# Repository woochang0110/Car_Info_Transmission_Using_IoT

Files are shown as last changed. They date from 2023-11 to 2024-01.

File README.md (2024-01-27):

# Car_Info_Transmission_Using_IoT
## IoT를 이용한 차량 정보 전송 및 활용<br><br>

아래 사진을 누르면 발표자료 페이지로 이동합니다.
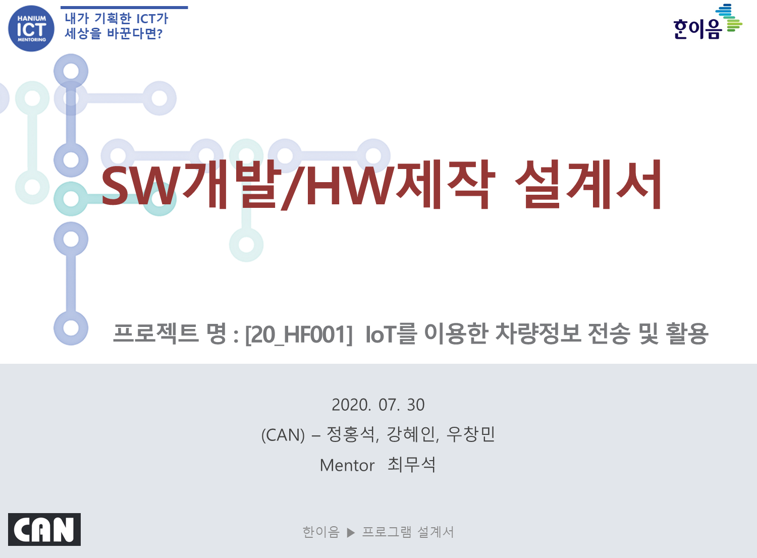
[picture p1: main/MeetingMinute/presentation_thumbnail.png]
Project Presentation
<br>
<br>

아래 사진을 누르면 프로젝트 개요서 페이지로 이동합니다.
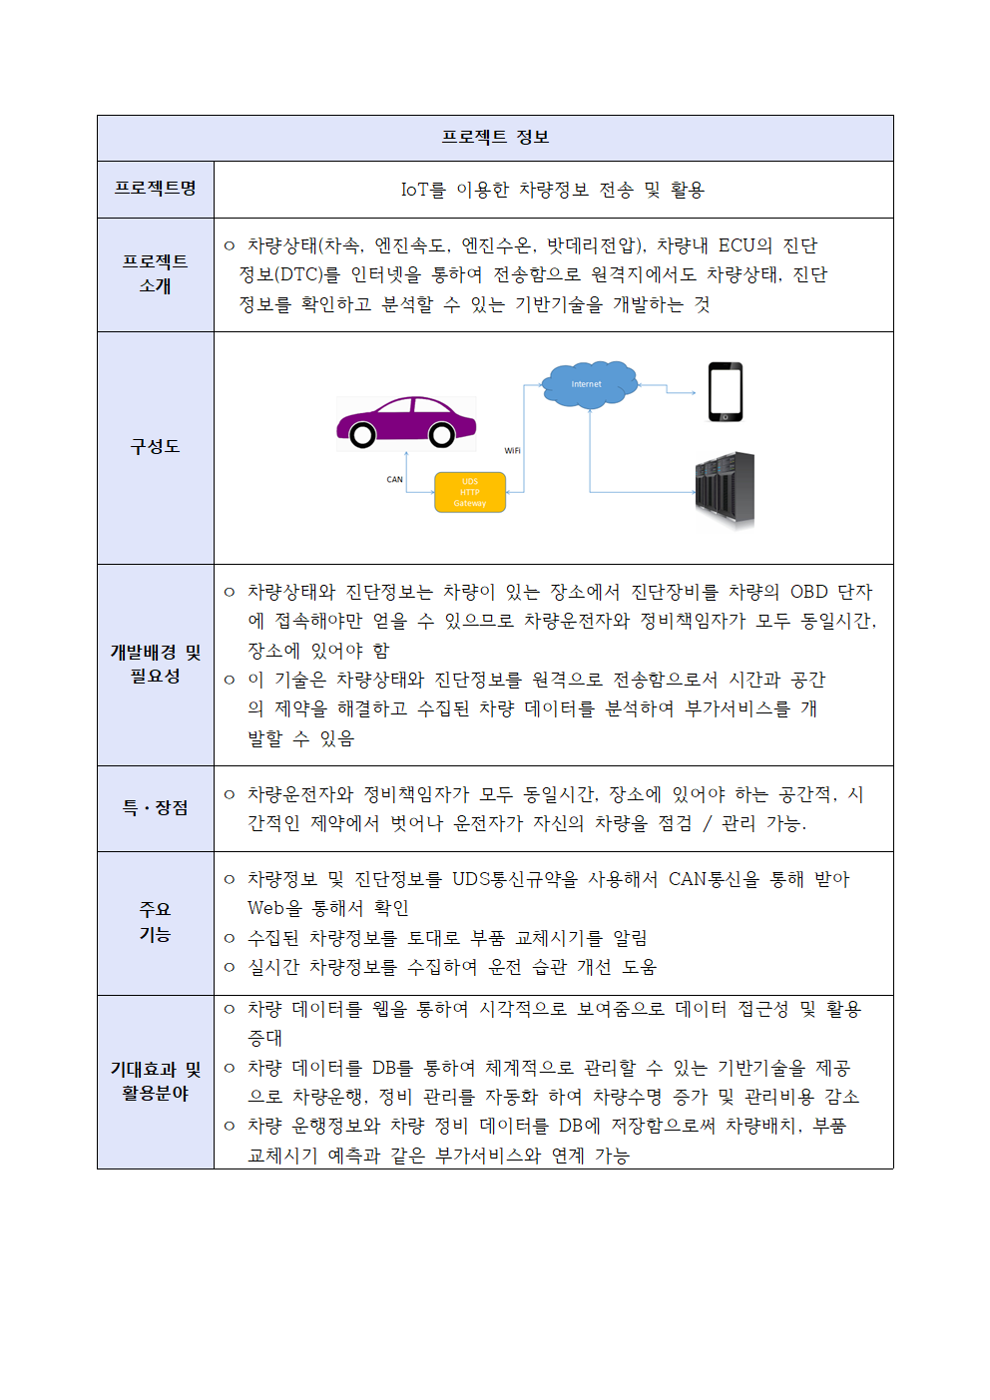
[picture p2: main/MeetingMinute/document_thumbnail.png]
<br>
<br>

아래 사진을 누르면 프로젝트 논문 페이지로 이동합니다.
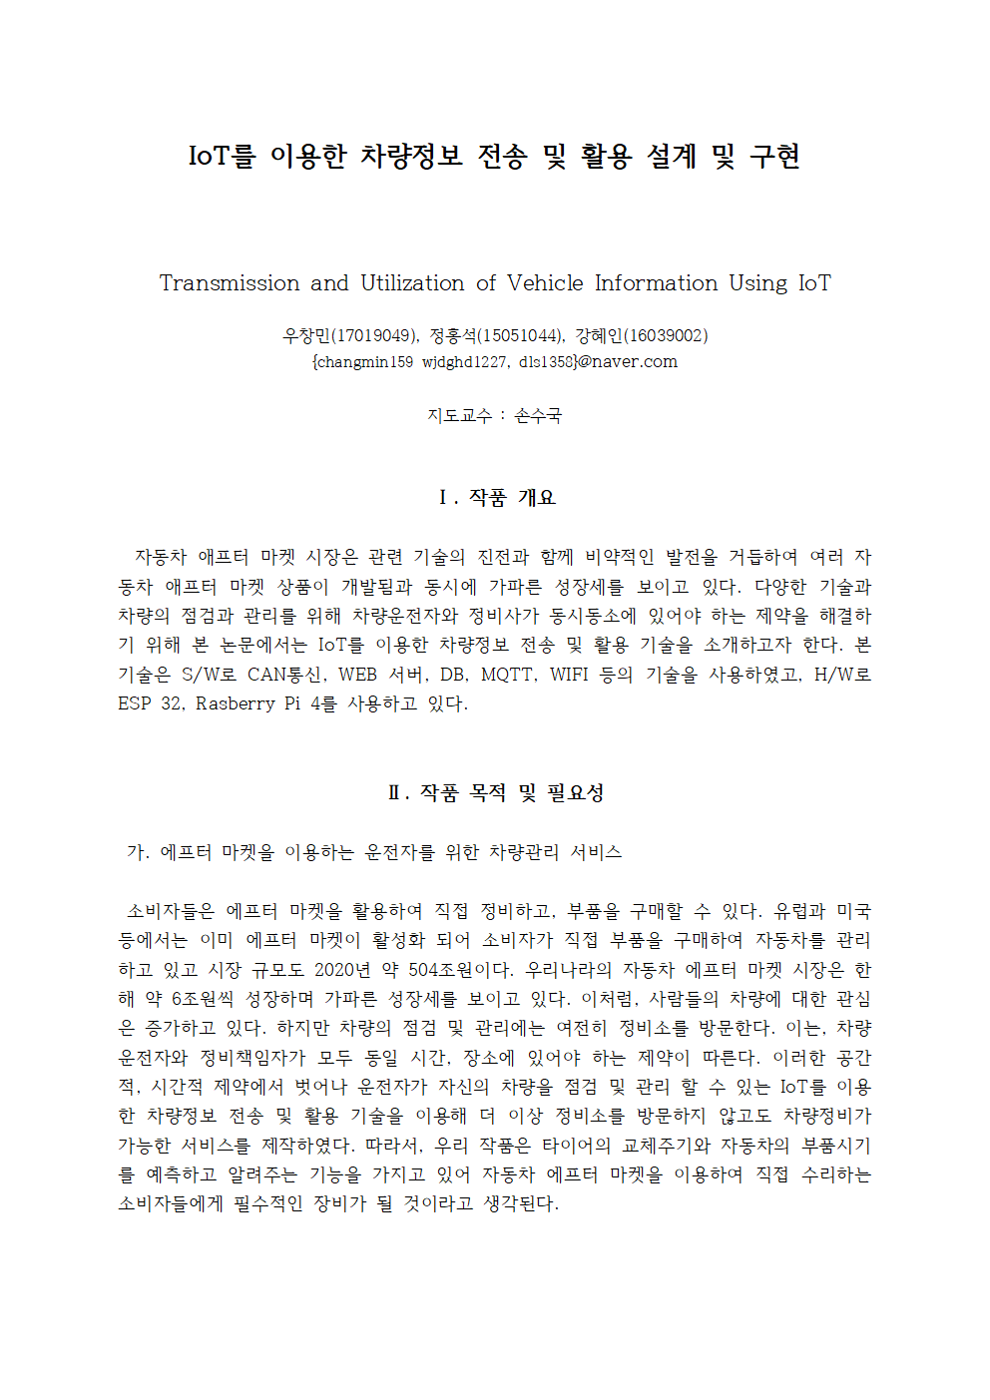
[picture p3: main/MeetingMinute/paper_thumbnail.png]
<br>
<br>

아래 사진을 누르면 데모 영상 링크로 이동합니다.
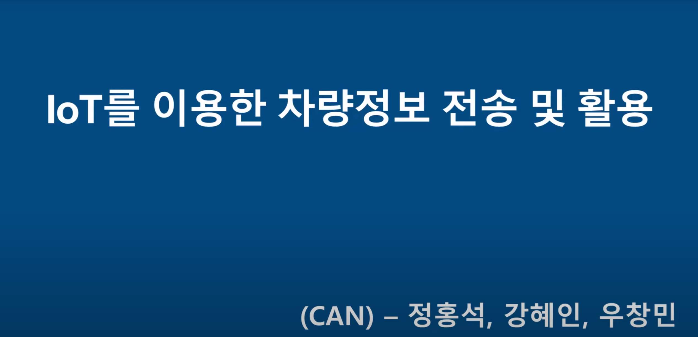
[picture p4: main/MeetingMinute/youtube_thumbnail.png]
Youtube (https://youtu.be/HxeCA7awFlk?si=O_MYcT4yE5AFmc94)
<br>

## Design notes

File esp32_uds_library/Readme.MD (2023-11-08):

ISO 14229-1 UDS protocol implementation for Arduino

This implementation requires ESP32_CAN lib

and ISO-TP-ESP32 lib from

Currently implemented:

* Send UDS SID with Userpayload
* Handle UDS Timeout
* Handle UDS Error

Missing:

* The Future will show

See usage example in example/uds/uds.ino
Request supported OBD2 PIDs see example/obd2/obd2.ino

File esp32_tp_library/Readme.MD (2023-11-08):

ISO 15765-2 ISO-TP protocol implementation for Arduino

This implementation requires ESP32 CAN library base on

...\Arduino\hardware\espressif\esp32\tools\sdk\include\driver\driver

Currently implemented:

* 11 bit standard CAN messages
* Send ISO-TP single frame messages
* Send ISO-TP multi frame messages using first and consecutive frames
* Evaluate flow controll and honour minimum separation time + block size during send
* Receive ISO-TP single frame messages
* Receive ISO-TP multi frame messages
* Send flow controll as configured in message (minimum separation time + block size)
* Session timeout
* FC timeout
* CF timeout
* Timeout after too many FC Wait messages
* some error handling
* simple frame padding with 0x00

See usage example in example/send_receive/send_receive.ino

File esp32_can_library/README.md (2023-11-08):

This ESP32 CAN librry base on

...\Arduino\hardware\espressif\esp32\tools\sdk\include\driver\driver

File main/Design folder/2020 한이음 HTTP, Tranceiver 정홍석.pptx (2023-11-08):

## 2020 한이음 IoT를 이용한 차량정보 조회 및 활용

SW 블록 다이어그램 및 플로우 차트

## SW FlowChart

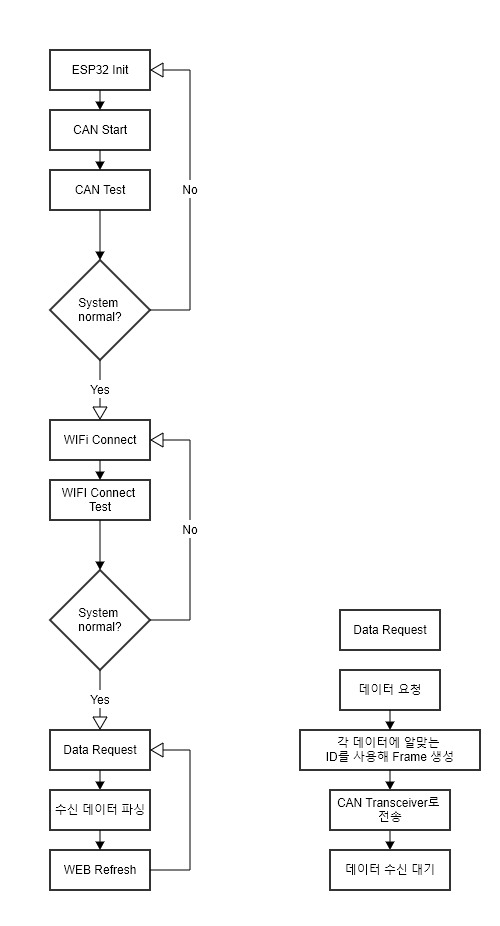
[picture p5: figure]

## 블록 다이어그램

<CAN Frame>

ID
(11bits)
(29bits)

DLC
(4bits)

Data

<CAN Message Frame>

ESP32

CAN Controller

CAN Transceiver

Tx

Rx

CAN_H

CAN_L

## 시스템 구성도

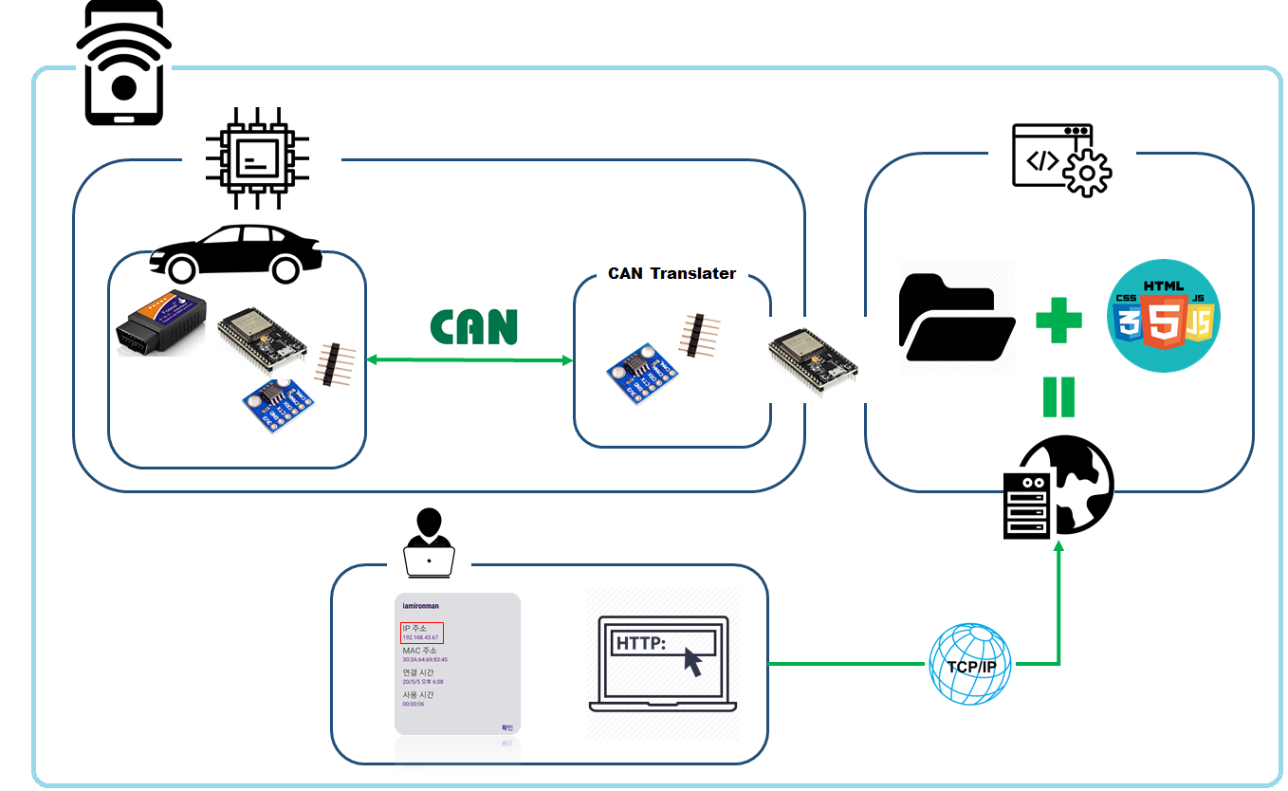
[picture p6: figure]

## SW 아키텍처

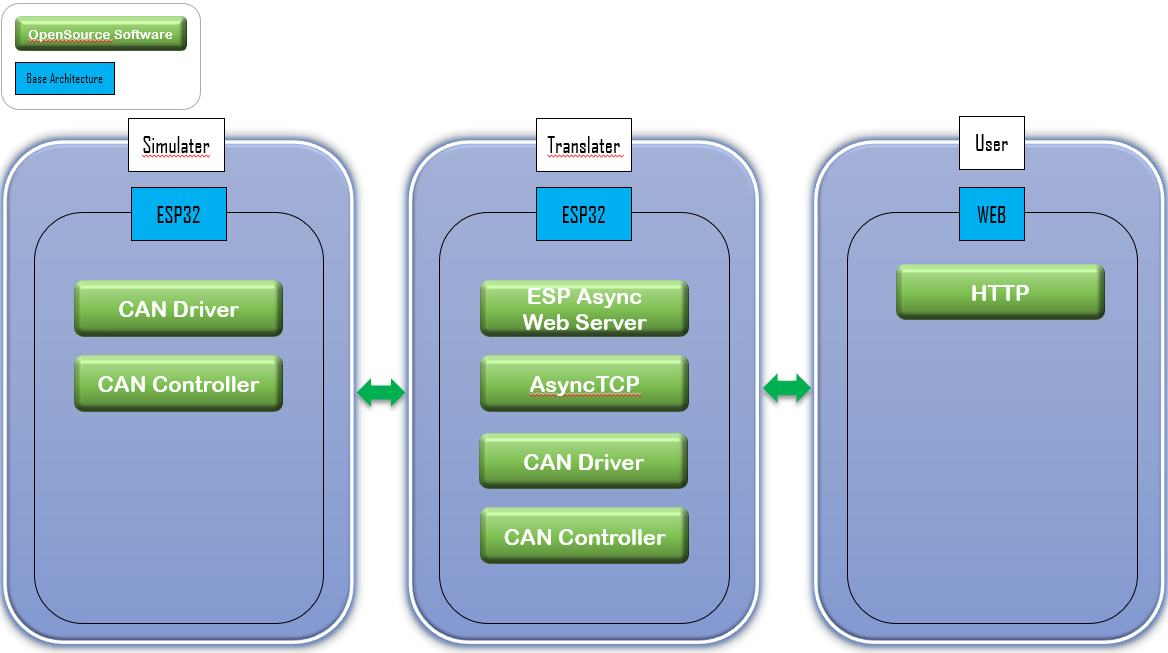
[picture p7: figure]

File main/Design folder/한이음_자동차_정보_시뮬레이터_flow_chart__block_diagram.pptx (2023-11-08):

## 자동차 정보 시뮬레이터

멘티 우창민

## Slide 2

시작

CAN 통신 가능?

YES

YES

YES

NO

IGN ON?

NO

RPM,주행거리,차속,연료잔량 값 세팅

RPM,주행거리,차속,연료잔량 값 임시저장

고장코드 값 임시저장

전송요청?

NO

임시 저장한 값들 전송

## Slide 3

스위치

버튼

IGN

고장코드

13

16

power

ESP-32

CAN

ESP-32

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
가변저항

가변저항

가변저항

가변저항

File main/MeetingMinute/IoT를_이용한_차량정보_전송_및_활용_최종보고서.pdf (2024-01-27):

- 1 -

# □ 서식4_한이음 ICT멘토링 프로젝트 결과보고서

2020 | 한이음 ICT멘토링
프로젝트명 | IoT를 이용한 차량정보 전송 및 활용

- 2 -

# 요 약 본

## 프로젝트 정보

주제영역 | ■ 생활 □ 업무 ■ 공공/교통 □ 금융/핀테크 □ 의료 □ 교육 □ 유통/쇼핑 □ 엔터테인먼트
기술분야 | ■ IoT □ 모바일 □ 데스크톱 SW □ 인공지능 □ 보안 □ 가상현실 □ 빅데이터 □ 자동제어기술 □ 블록체인 □ 영상처리
달성성과 | ■ 논문게재 및 포스터발표 □ 앱등록 □ 프로그램등록 □ 특허 □ 기술이전 □ 실용화 ■ 공모전(2020 한이음 공모전 ) □ 기타( )
프로젝트명 | IoT를 이용한 차량정보 전송 및 활용
프로젝트 소개 | ㅇ 차량상태(차속, 엔진속도, 엔진수온, 밧데리전압), 차량내 ECU의 진단 정보(DTC)를 인터넷을 통하여 전송함으로 원격지에서도 차량상태, 진단 정보를 확인하고 분석할 수 있는 기반기술을 개발하는 것
개발배경 및 필요성 | ㅇ 차량상태와 진단정보는 차량이 있는 장소에서 진단장비를 차량의 OBD 단 자에 접속해야만 얻을 수 있으므로 차량운전자와 정비책임자가 모두 동일 시간, 장소에 있어야 함 ㅇ 이 기술은 차량상태와 진단정보를 원격으로 전송함으로서 시간과 공간 의 제약을 해결하고 수집된 차량 데이터를 분석하여 부가서비스를 개 발할 수 있음
프로젝트 주요기능 | ㅇ 차량정보 및 진단정보를 UDS통신규약을 사용해서 CAN통신을 통해 받아 Web을 통해서 확인 ㅇ 수집된 차량정보를 토대로 부품 교체시기를 알림 ㅇ 실시간 차량정보를 수집하여 운전 습관 개선 도움
작품의 기대효과 및 활용분야 | ㅇ 차량 데이터를 웹을 통하여 시각적으로 보여줌으로 데이터 접근성 및 활용 증대 ㅇ 차량 데이터를 DB를 통하여 체계적으로 관리할 수 있는 기반기술을 제공 으로 차량운행, 정비 관리를 자동화 하여 차량수명 증가 및 관리비용 감소 ㅇ 차량 운행정보와 차량 정비 데이터를 DB에 저장함으로써 차량배치, 부품 교체시기 예측과 같은 부가서비스와 연계 가능

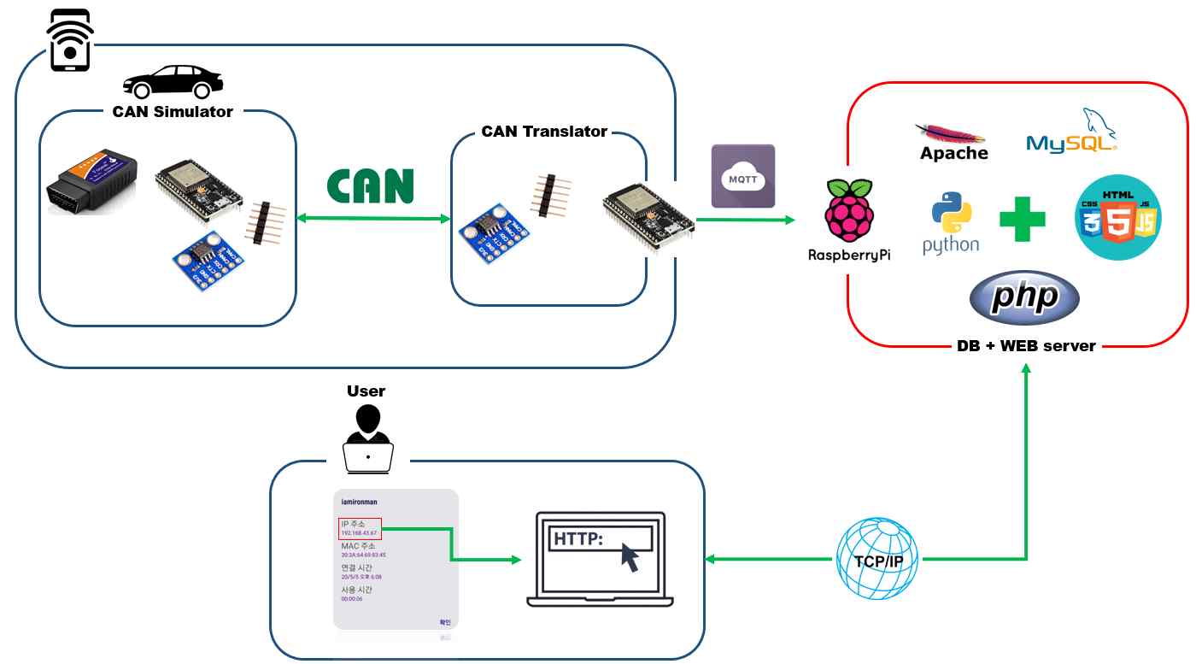
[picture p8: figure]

- 3 -

# (본문) 프로젝트 결과보고서

# Ⅰ. 프로젝트 개요

# 가. 프로젝트 소개

# ㅇ차량상태(차속, 엔진속도, 엔진수온, 밧데리전압), 차량내 ECU의 진단정보(DTC)를

# 인터넷을 통하여 전송함으로 원격지에서도 차량상태, 진단정보를 확인하고 분석할 수 있는 기반기술 개발하는 것

# 나. 개발배경 및 필요성

# ㅇ 차량상태와 진단정보는 차량이 있는 장소에서 진단장비를 차량의 OBD 단자에

# 접속해야만 얻을 수 있으므로 차량운전자와 정비책임자가 모두 동일시간, 장소

존재해야 함.

# ㅇ 접근성에서 가장 뛰어난 수단은 WEB이라 생각했고, WEB 서비스를 통해 차량

# 정보를 관제할 수 있는 시스템 개발 시작. ㅇ 이 프로젝트를 통해 차량상태와 진단정보를 MQTT를 이용해서 원격으로 전송

# 함으로서 시간과 공간의 제약을 해결하고 수집된 차량 데이터를 분석하여 부가 서비스를 개발 가능. 다. 작품 구성도

- 4 -

# 라. 작품의 특징 및 장점

ㅇ 차량운전자와 정비책임자가 모두 동일시간, 장소에 있어야 하는 공간적,

시간적인 제약에서 벗어나 운전자가 자신의 차량을 점검 / 관리 가능.

ㅇ 기존 기술인 OBD2를 이용해서 차량상태를 진단 및 데이터 저장.

ㅇ 수집된 데이터를 웹 페이지에서 시각적으로 표현.

ㅇ 총 주행거리 데이터를 사용해 차량의 부품 교체 시기 예측.

# Ⅱ. 프로젝트 수행결과

# 가. 업무분장

번호 | 성명 | 역할 | 담당업무
1 | 최무석 | 멘 토 | - 미팅 계획 수립, 멘토링
3 | 우창민 | 팀 장 | - SW1, 3D 프린팅
4 | 정홍석 | 팀 원2 | - SW2
5 | 강혜인 | 팀 원3 | - HW

# 나. 주요기능

구분 | 기능 | 설명
S/W | UDS 통신 | 차량상태를 받아오기 위해 차량과 UDS 통신. WIFI를 통한 DB와의 연동
| 받아온 데이터들을 DB에 저장. DB에 저장된 값들을 보여주기 위해 웹서버 활용. 웹 페이지 상에
| 출력 | 실시간 정보, 통계 페이지, 소모품 교체 주기, 고장코드 정보를 웹을 통해 출력
H/W | UDS, HTTP Translator 하드웨어 | - ESP32와 CAN transceiver로 구성되어 자동 차 CAN 네트워크 데이터를 WiFi 네트워크로 전송
| UDS Simulator 하드웨어 | - ESP32와 CAN transceiver로 구성되어 자동 차 상태정보, 진단정보를 시뮬레이션

- 5 -

# 다. 프로젝트 개발환경

구분 | 항목 | 적용내역
S/W 개발환경 | OS | Window10, Rasbian | 개발에 사용된 운영체제
| 개발환경(IDE) | Arduino IDE (1.8.9) | esp-32 개발 시 사용
| 개발도구 | Visual Studio Code | 코드 수정 시 사용
| 개발언어 | C++, Python, PHP, Javascript | 웹서버, DB 제작에 사용
H/W 구성장비 | 디바이스 | ESP32, CAN transceiver, 가변저항, 토글 스위치 | 프로젝트에 사용된 디바이스
| 센서 | x | x
| 통신 | CAN, OBD, UDS, MQTT | 차량과의 통신을 위해 사용한 통신 프로토콜
| 개발언어 | C++ | esp-32 개발에 사용된 언어

# 라. 장비(기자재/재료) 활용

번호 | 품명 | 작품에서의 주요기능
1 | ESP-32 | - 시뮬레이터, 트랜스레이터로 사용
2 | CJMCU-230 | - 캔 트랜시버로 사용
3 | 라즈베리파이 4 | - 웹서버, DB 구동에 사용
4 | 3D 프린터 | -3D 프린팅에 사용

# 마. 프로그램 작동 동영상

# ㅇ https://youtu.be/HxeCA7awFlk

# 바. 결과물 상세 이미지

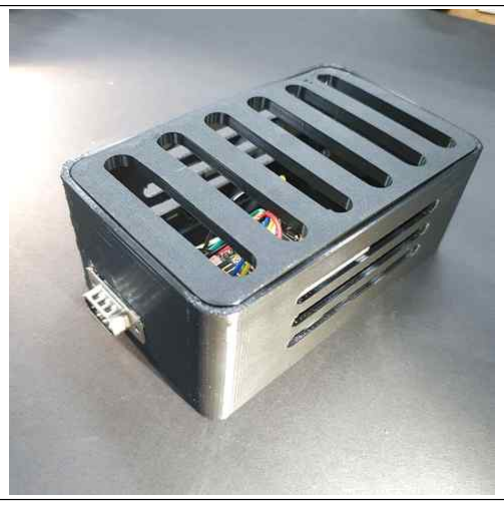
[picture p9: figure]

- 6 -

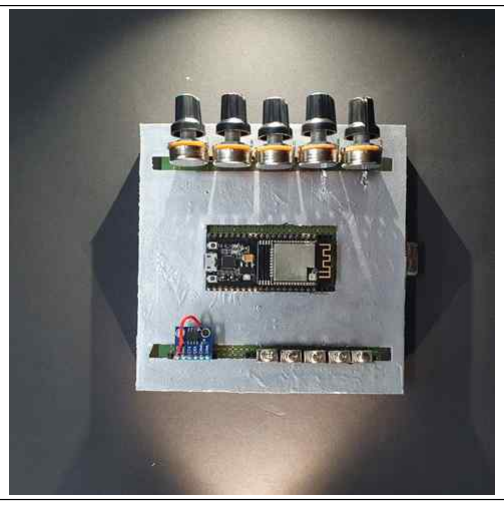
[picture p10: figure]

# 사. 달성성과

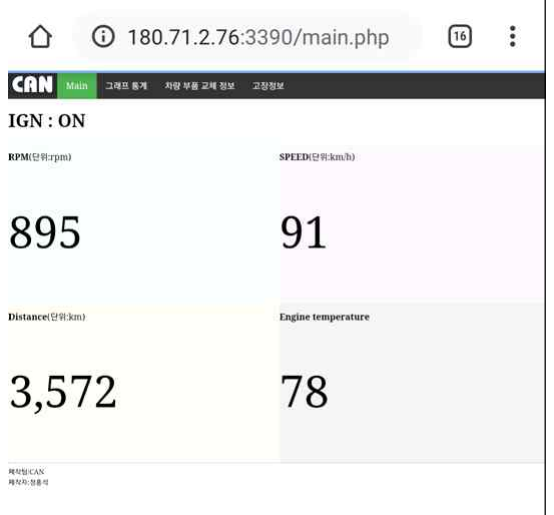
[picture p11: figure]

# ㅇ 기존 기획 의도대로 차량상태(차속, 엔진속도, 엔진수온, 밧데리전압), 차량내

# ECU의 진단정보(DTC)를 인터넷을 통하여 전송함으로 원격지에서도 차량상태, 진

단정보를 확인하고 분석할 수 있는 기반기술을 개발하는 성과를 달성하였음.

■

## 논문게재 및

### 포스터발표

게재(발표)자명 | 논문(포스터)명 | 게재(발표)처 | 게재(발표)일자
우창민 | IoT를 이용한 차량정보 전송 및 활용 설계 및
구현 | 한 국 정 보 처 리 학 회 2017. 00. 00.

□

### 앱(APP)

등록

등록자명 | 앱(APP)명 | 등록처 | 등록일자
| | | 2017. 00. 00.

□

### 프로그램

등록

등록자명 | 프로그램명 | 등록처 | 등록일자
| | | 2017. 00. 00.

□

## 특허/실용신안

출원

출원자명 | 특허/실용신안명 | 출원번호 | 출원일자
| | | 2017. 00. 00.

## □ 기술이전

기술이전기업명 | 기술명 | 금액 | 이전일자
| | | 2017. 00. 00.

### ■ 공모전

구분(교내/대외) | 공모전명 | 수상여부(출품/수상) | 상격
대외 | 2020 한이음 공모전 | 입선

## □ 실용화

## #실용화한 내용에 대한 구체적 작품설명

□ 기타

# Ⅲ. 프로젝트 수행방법

# 가. 프로젝트 수행일정

- 7 -
구분 | 추진내용 | 수행일정
3월 | 4월 | 5월 | 6월 | 7월 | 8월 | 9월 | 10월 | 11월
계획 | Kickoff 미팅, 팀구성, 업무분장, 개발계획 | | 11
분석 | UDS, HTTP gateway 기능분석 | | 20
설계 | HW1,2 회로설계 | | | 1
| SW1 설계 | | | 1
| SW2 설계 | | | 1
개발 | HW1,2 개발&3D 프린팅 | | | | 1
| SW1 개발 | | | | | 1
| SW2 개발 | | | | | 1
| 외부 서버 개발
테스트 | HW1과 SW1, HW2와 SW2 통합 테스트 | | | | | | | 1
종료 | 테스트결과 반영, 개선, 결과보고서 | | | | | | | | 31
오프라인 미팅계획 | Skype를 이용한 온라인 미팅 | | 25 | 9,23 | 6,20 | 4,18 | 2,15, 29 | 12,2 6 | 10,2 4 | x

# 나. 문제점 및 해결방안

# ㅇ 프로젝트 관리 측면

# *문제점

- 하드웨어 가공기술 및 공구부족으로 하드웨어 개발일정 지연.

# *해결방안

- 추가 공구(3D 프린터) 구매 및 가공기술 습득을 위해 시간 투자.

# ㅇ 작품 개발 측면

# *문제점 - CAN통신을 위한 CAN 모듈의 결함으로 인한 프로젝트 개발일정 지연. - 자동차 정보 수집용 서버를 외부에 설치하는 것으로 변경하여 추가개발일정

발생.

# *해결방안

- CAN Tranceiver 모듈의 Vref핀 전압을 증가시킴으로써 문제 해결.

# - 라즈베리파이를 이용해 MQTT 서버와 웹서버 구축하여 차량데이터 전송

효율을 높임.

- 8 -

# Ⅳ. 기대효과 및 활용분야

# ㅇ 차량 데이터를 웹을 통하여 시각적으로 보여줌으로 데이터 접근성 및 활용성

# 증대. ㅇ 차량 데이터를 DB를 통하여 체계적으로 관리할 수 있는 기반기술을 제공함으로

# 차량운행, 정비 관리를 자동화 하여 차량수명 증가 및 관리비용 감소. ㅇ 차량 운행정보와 차량 정비 데이터를 DB에 저장함으로써 차량배치, 부품 교체

시기 예측과 같은 부가서비스와 연계 가능.

# Ⅴ. 참고자료

# 가. 참고 및 인용자료

ㅇ Seo-Kyung Lee, Jae-Yong Lee, Dong-Hyun Kim, Kwang-Joo Choi,
Jae-IlJung,CAN | Communication | System | using CAN | Protocol, | Korea

# Information Processing Society, Republic of Korea, 2006, 4

# ㅇ M. Farsi, K. Ratcliff and M. Barbosa, "An overview of controller area

network," in Computing & Control Engineering Journal, vol. 10,

# no.3,pp.113-120,June 1999, doi: 10.1049/cce:19990304

- 9 -

# [별첨] 한이음 ICT멘토링 프로젝트 산출물

# 한이음 ICT멘토링 프로젝트 산출물

# 1. 한이음 공모전 입선 ······················································0

# 2. 2020 온라인 추계학술 발표대회 참가 ····················0

# 3. 소스코드 ··········································································0

# 1. 한이음 공모전 입선

# 2. 2020년 온라인 추계학술 발표대회 참가

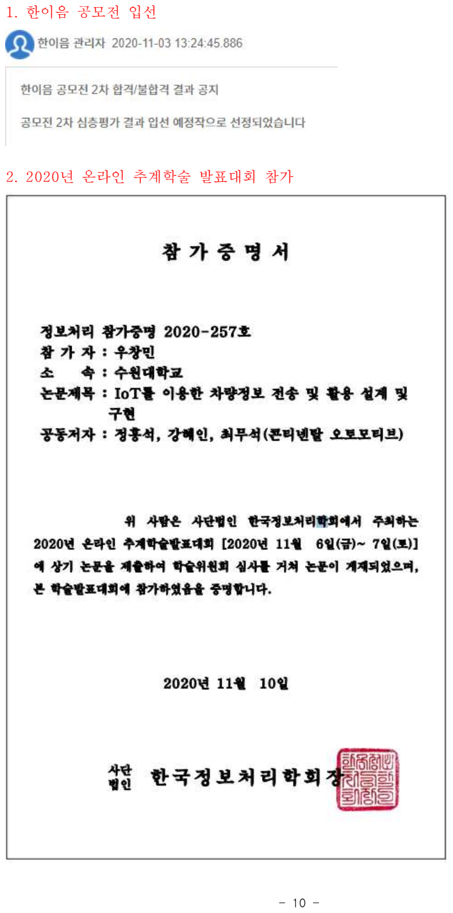
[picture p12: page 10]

- 10 -

- 11 -

# 3. 소스코드

## *CAR Simulator

#include <esp32_can.h>

#include <iso-tp-esp32.h>

#include <uds-esp32.h>

ESP32_CAN CAN0;
IsoTp isotp(&CAN0);
UDS uds(&isotp);
struct Session_t session;
//가변저항
const int CoolantTemp_pin = 34; const int Odometer_pin = 35; const int EngineRpm_pin = 32; const int VehicleSpeed_pin = 33; const int EngineFuelRate_pin = 25; //스위치
const int Error_Code1_pin = 5; const int Error_Code2_pin = 22; const int Error_Code3_pin = 18; const int IGN_pin = 21;
const int Auto_Simulator_pin = 19;
//함수
void AutoSimulator_OBD2(uint32_t Max, uint8_t bitarray[], int digit ); void AutoSimulator_UDS();
void hex_converter_8(uint32_t num, uint8_t bitarray[], int digit); //PID Data Array
uint8_t pidSupport0x01To0x20[] = {0x08, 0x18, 0x00, 0x00};
uint8_t pidSupport0x81To0xA0[] = {0x00, 0x00, 0x00, 0x08};
uint8_t pidSupport0xA1To0xC0[] = {0x04, 0x00, 0x00, 0x00};
uint8_t pid0x05CoolantTemp[] = {0x78}; // 0x78 = 120 => 120 - 40 = 80 C
uint8_t pid0x0CEngineRpm[] = {0x1F, 0x40}; // 0x1F 40 = 8000 => 8000/ 4 = 2000 rpm
uint8_t pid0x0DVehicleSpeed[] = {0x64}; // 0x64 = 100 Km/h
uint8_t pid0x9DEngineFuelRate[] = {0x3C}; //0x3C=60L
uint8_t pid0xA6Odometer[] = {0x00, 0x01, 0x86, 0xA0}; //0x00 01 86 A0=100000 =>100000/10=10000km //DTC Data Array
uint8_t P00BBFuelInjectorInsufficientFlow[] = {0x00, 0xBB};
uint8_t B0020LeftSideAirbagDeploymentControl[] = {0x80, 0x20};
uint8_t C0281BrakeSwitchCircuit[] = {0x42, 0x81};
//PID Struct
#define NUM_PIDS 8

struct {
uint8_t pid;
uint8_t* Data;
} responseData[NUM_PIDS] = { {0, pidSupport0x01To0x20}, {0x05, pid0x05CoolantTemp}, {0x0C, pid0x0CEngineRpm}, {0x0D, pid0x0DVehicleSpeed}, {0x80, pidSupport0x81To0xA0}, {0x9D, pid0x9DEngineFuelRate}, {0xA0, pidSupport0xA1To0xC0}, {0xA6, pid0xA6Odometer}

};
//DTC Struct
#define NUM_DTCS 3

struct {
int value;
uint8_t* Data;
} responseDTC[NUM_PIDS] = { {0, P00BBFuelInjectorInsufficientFlow}, {0, B0020LeftSideAirbagDeploymentControl}, {0, C0281BrakeSwitchCircuit}

};
void setup() {
// put your setup code here, to run once:

- 12 -

Serial.begin(115200);
// Initialize ESP32 CAN with a baudrate of 500kb/s and tx pin 16, rx pin 17. if (CAN0.begin(16, 17, CAN_500KBPS) == CAN_OK) {

Serial.println("ESP32 CAN Initialized Successfully!");
} else {
Serial.println("Error Initializing ESP32 CAN..."); return;
}
pinMode(5, INPUT); // 고장코드 1
pinMode(22, INPUT); // 고장코드 2 pinMode(18, INPUT); // 고장코드 3 pinMode(21, INPUT); // IGN ON pinMode(19, INPUT); //auto simulator delay(5000);
}#define LEN_DATA 8
void loop() {
uint8_t rxData[LEN_DATA];
uint8_t txData[LEN_DATA];
struct Session_t diag;
uint16_t retval = 0;
uint8_t pid;
int IGN = digitalRead(IGN_pin); if (!IGN) {//IGN OFF
Serial.println("IGN OFF");
}
else {//IGN ON
Serial.println("IGN ON");
int AutoSimul = digitalRead(Auto_Simulator_pin); if (!AutoSimul) {//Auto Simulator OFF Serial.println("Auto Simulator OFF"); Serial.println("Odometer ");
int reading_Odometer = analogRead(Odometer_pin); Serial.println(reading_Odometer);
uint32_t Odometer = reading_Odometer * 488; //실질적인 값을 표현하기 위해 Serial.println(Odometer);
hex_converter_8(Odometer, pid0xA6Odometer , 8);
Serial.println();
// TODO : Need to consider fomular, min, max of PDI tabale. //temperature=A-40

int reading_CoolantTemp = analogRead(CoolantTemp_pin); int CoolantTemp = map(reading_CoolantTemp, 0, 4095, 0, 255); Serial.println("Engine Temperature"); hex_converter_8(CoolantTemp, pid0x05CoolantTemp , 2); Serial.println();
//RPM =A-40
int reading_EngineRpm = analogRead(EngineRpm_pin);
uint16_t EngineRpm = map(reading_EngineRpm, 0, 4095, 0, 65535); Serial.println("Engine RPM");
hex_converter_8(EngineRpm, pid0x0CEngineRpm , 4); Serial.println();
int reading_VehicleSpeed = analogRead(VehicleSpeed_pin); int VehicleSpeed = map(reading_VehicleSpeed, 0, 4095, 0, 255); Serial.println("Vehicle Speed");
hex_converter_8(VehicleSpeed, pid0x0DVehicleSpeed , 2); Serial.println();
int reading_EngineFuelRate = analogRead(EngineFuelRate_pin); int EngineFuelRate = map(reading_EngineFuelRate, 0, 4095, 0, 60); Serial.println("Engine Fuel Rate");
hex_converter_8(EngineFuelRate, pid0x9DEngineFuelRate , 2); Serial.println();
responseDTC[1].value = digitalRead(Error_Code1_pin); responseDTC[2].value = digitalRead(Error_Code2_pin); responseDTC[3].value = digitalRead(Error_Code3_pin); }

- 13 -

else {//Auto Simulator ON
Serial.println("Auto Simulator ON"); AutoSimulator_OBD2(2000000, pid0xA6Odometer, 8 ); AutoSimulator_OBD2(255, pid0x05CoolantTemp, 2 ); AutoSimulator_OBD2(65535, pid0x0CEngineRpm, 4 ); AutoSimulator_OBD2(255, pid0x0DVehicleSpeed, 2 ); AutoSimulator_OBD2(60, pid0x9DEngineFuelRate, 2 ); AutoSimulator_UDS();
}
//Array에 data는 다 들어감
//-> DATA 전송
if (retval = uds.SessionServer(&diag))
{
Serial.println(F("No OBD request from tool.")); }
else
{
Serial.print(F("request SID: ")); Serial.println(diag.sid); //OBD2 DATA 전송
if (diag.sid == OBD_MODE_SHOW_CURRENT_DATA) { pid = diag.Data[0];
Serial.print(F("request PID: ")); Serial.println(pid); Serial.print(F("request data: "));
for (uint8_t i = 1; i < diag.len; i++)
{
Serial.print(diag.Data[i]); Serial.print(F(" ")); }
Serial.println();
memset(txData, 0, LEN_DATA);
for (uint8_t i = 0; i < NUM_PIDS; i++)
{
if (responseData[i].pid == pid) // Find the required pid data {
diag.sid = diag.sid + 0x40; // Add 0x40 to received sid txData[0] = pid;
uint8_t lenPidValue = sizeof(responseData[i].Data); memcpy(txData + 1, responseData[i].Data, lenPidValue); diag.Data = txData;
diag.len = lenPidValue + 1;
retval = uds.serverResponse(&diag);
}
}
}
//UDS 고장진단코드 전송
if (diag.sid == OBD_MODE_READ_DTC) { Serial.println("UDS start...");
int count = 0;// DTC 갯수
for (int i = 0; i < NUM_DTCS; i++) { if (responseDTC[i].value) { count++;
}
}
memset(txData, 0, 2 * count);
if (count == 0) {//DTC가 하나도 없을 때 Serial.println("No DTC");
diag.Data = 0;
diag.len = 4;
retval = uds.serverResponse(&diag);
}
else { //DTC 1개라도 있을떄
diag.sid = diag.sid + 0x40; // Add 0x40 to received sid
if (count == 1) {//DTC 1개
Serial.println(" 1 DTC");
for (int i = 0; i < NUM_DTCS; i++) {//on인 DTC 1개 찾아서 전송

- 14 -

if (responseDTC[i].value) {
uint8_t lenDTCValue = sizeof(responseDTC[i].Data); memcpy(txData, responseDTC[i].Data, lenDTCValue); diag.Data = txData;
diag.len = 2 * count;
retval = uds.serverResponse(&diag);
}
}
}//DTC 1개 close
else if (count == 2) {//DTC 2개 Serial.println(" 2 DTC ");
for (int i = 0; i < NUM_DTCS; i++) {
if (responseDTC[i].value) {
uint8_t lenDTCValue = sizeof(responseDTC[i].Data); memcpy(txData + 2 * i, responseDTC[i].Data, lenDTCValue); }
}
diag.Data = txData;
diag.len = 4;
retval = uds.serverResponse(&diag); }//DTC 2개 close
else if (count == 3) {//DTC 3개
Serial.println(" 3 DTC ");
for (int i = 0; i < NUM_DTCS; i++) {
uint8_t lenDTCValue = sizeof(responseDTC[i].Data); memcpy(txData + 2 * i, responseDTC[i].Data, lenDTCValue); }
diag.Data = txData;
diag.len = 6;
retval = uds.serverResponse(&diag); }//DTC 3개 close
}//DTC 1개라도 있을때 close
}//sid=dtc close
}
delay(1000);
}
}void AutoSimulator_OBD2(uint32_t Max, uint8_t bitarray[], int digit ) { uint32_t value = random(0, Max);
hex_converter_8(value, bitarray, digit);
}void AutoSimulator_UDS() {
for (int i = 0; i < NUM_DTCS; i++) {
responseDTC[i].value = random(0, 2);
}
}void hex_converter_8(uint32_t num, uint8_t bitarray[], int digit) { //들어온 값 , 값을 분해해서 넣을 배열, 배열이 8bit로 몇개 구성되어 있는지 int pos = digit;
int temp[digit] = { 0 }; // 16진수로 된 문자열을 임시저장할 배열 (순서 제대로임)
uint32_t decimal = num;
Serial.println();
for (int i = 0; i < pos; i++) {
if (decimal < 16) {
temp[pos - i - 1] = decimal;
}
temp[pos - i - 1] = decimal % 16;
decimal = decimal / 16;
Serial.print(temp[pos - i - 1]); Serial.print(" "); }
Serial.print(" 0x");
for (int j = 0; j < pos / 2; j++) {
bitarray[j] = temp[2 * j] * 16 + temp[2 * j + 1]; //int로 잘려져있는 값들을 8비트 배열에 차곡차곡 넣어줌 if (bitarray[j] < 16) {
Serial.print("0");
}
Serial.print(bitarray[j], HEX); Serial.print(" "); }

- 15 -

}

## *CAR Translator

# include <esp32_can.h>

# include <iso-tp-esp32.h> # include <uds-esp32.h>

# include <WiFi.h>

# include <PubSubClient.h>

# define MSG_BUFFER_SIZE (50) # define BUILTIN_LED 25

ESP32_CAN CAN0;
IsoTp isotp(&CAN0);
UDS uds(&isotp);
struct Session_t session;
char msg[MSG_BUFFER_SIZE];
const char* ssid = "Hong";
const char* password = "123456789q"; const char* mqtt_server = "180.71.2.76"; uint8_t tmp[] = {};
String packet;
long lastMsg = 0;
// 웹에 나타나는 정보 변수 초기화
int IGN = 0;
int RPM = 0;
int D = 0;
int V = 0;
int Eng_temp = 0;
int Fuel_level = 0;
WiFiClient esp_client;
PubSubClient client(esp_client); // 사용되는 함수 초기화
void displayWifistatus(void);
void OBD2_receiver(uint8_t pid);
void UDS_receiver(void);
long data_process(int count, uint8_t *array_pointer);
void mqtt_trans(int IGN, int (RPM), double D, int V, float Eng_temp, int Fuel_level); void callback(char* topic, byte* payload, unsigned int length);
void reconnect();
void setup() {
// put your setup code here, to run once: Serial.begin(115200);
Serial.println();
//1. wifi연결
WiFi.begin(ssid, password); Serial.println("Connecting");
while (WiFi.status() != WL_CONNECTED) {
displayWifistatus();
delay(500);
}
displayWifistatus();
Serial.println();
Serial.print("Conncected, IP address: "); Serial.println(WiFi.localIP()); Serial.print("Gateway IP: "); Serial.println(WiFi.gatewayIP()); Serial.print("RSSI: ");
Serial.println(WiFi.RSSI());
//2. Mqtt 연결
pinMode(BUILTIN_LED, OUTPUT); client.setServer(mqtt_server, 1883); client.setCallback(callback);

//3. CAN 연결

- 16 -
if (CAN0.begin(16, 17, CAN_500KBPS) == CAN_OK) { | //25,50,100,125,250,500,800,1000
Serial.println("ESP32 CAN Initialized Successfully!");
} else {
Serial.println("Error Initializing ESP32 CAN...");
return;
}
delay(5000);
}void loop() {
uint8_t pid[] = {0x1F, 0x05, 0x0C, 0x0D, 0x9D, 0xA6}; uint8_t uds_id[] = {};
//1. OBD2로 Data receive
for (int i = 0; i < sizeof(pid) / sizeof(uint8_t) ; i++) OBD2_receiver(pid[i]);
//2. UDS로 Data receive
UDS_receiver();
if (RPM != 0) | //엔진이 켜져있다면
IGN = 1; | //IGN을 True로
else | //엔진이 꺼져있다면
IGN = 0; | //IGN을 False로
if (IGN == 1); | //3. 시동이 켜져있다면
mqtt_trans(IGN); | //4. MQTT를 이용해 서버로 전송
}void displayWifistatus(void) {
Serial.print("ESP WiFi connection status: ");
switch (WiFi.status()) {
case 0:
Serial.println("WL_IDLE_STATUS"); break;
case 1:
Serial.println("WL_NO_SSID_AVAIL"); break;
case 3:
Serial.println("WL_CONNECTED"); break;
case 4:
Serial.println("WL_CONNECT_FAILED"); break;
case 6:
Serial.println("WL_DISCONNECTED"); break;
default:
Serial.println("Unknown status");
}
}void callback(char* topic, byte* payload, unsigned int length) { Serial.print("Message arrived [");
Serial.print(topic);
Serial.print("] ");
for (int i = 0; i < length; i++) { Serial.print((char)payload[i]);
}
Serial.println();
// Switch on the LED if an 1 was received as first character
if ((char)payload[0] == '1') {
digitalWrite(BUILTIN_LED, LOW); // Turn the LED on (Note that LOW is the voltage level // but actually the LED is on; this is because

// it is active low on the ESP-01)
} else {
digitalWrite(BUILTIN_LED, HIGH); // Turn the LED off by making the voltage HIGH }
}void reconnect() {
// Loop until we're reconnected
while (!client.connected()) { Serial.print("Attempting MQTT connection..."); // Create a random client ID
String clientId = "ESP8266Client-";

- 17 -

clientId += String(random(0xffff), HEX); // Attempt to connect
if (client.connect(clientId.c_str())) { Serial.println("connected");
// Once connected, publish an announcement... client.publish("start", "Connected Mqtt...");

// ... and resubscribe
client.subscribe("inTopic");
} else {
Serial.print("failed, rc="); Serial.print(client.state()); Serial.println(" try again in 5 seconds"); // Wait 5 seconds before retrying delay(5000);
}
}
}void OBD2_receiver(uint8_t pid) { int num = 0;
int count = 0;
long f_result = 0;
struct Session_t diag;
uint16_t retval = 0;
Serial.print(F("OBD2 request PIDs: ")); Serial.println(pid);
for (int i = 0; i < 1; i++) {
uint16_t rx_id_array[] = {0x7E9, 0x7E9};
diag.tx_id = 0x7DF; //0x7E0, 0x7DF -> 7DF였으면 원래 응답이 와야하는대 안됐음. // | 예제 하나 줄테니 실제 차량에서 진행해보자. //

diag.rx_id = rx_id_array[i];
Serial.print("tx_id : "); Serial.println(diag.tx_id); Serial.print("rx_id : "); Serial.println(diag.rx_id); //diag.rx_id = 0x7E8;
diag.sid = OBD_MODE_SHOW_CURRENT_DATA; diag.Data = &pid;
diag.len = 1;
if (retval = uds.Session(&diag))
{
Serial.print(F("OBD2 Error ")); Serial.print(retval);
Serial.print(F(" NRC "));
Serial.println(retval, HEX);
}
else
{
//0x1F, 0x05, 0x0C, 0x0D, 0x9D, 0xA6 //pid별 최대 바이트로 자르는 코드 시작
//1.각 pid별로 몇바이트인지 count변수에 저장 switch (pid) {
case 0x05:
count = 1;
//2. count만큼 데이터를 자르고 저장 tmp배열에 임시 저장 for (int i = 0; i < count; i++) {
tmp[i] = diag.Data[i];
}
//3. 데이터 후처리
Eng_temp = data_process(count, tmp) - 40; Serial.println("엔진 온도");
Serial.println(Eng_temp);
break;
case 0x0C:
count = 2;
//2. count만큼 데이터를 자르고 저장 tmp배열에 임시 저장 for (int i = 0; i < count; i++) {
tmp[i] = diag.Data[i];

- 18 -

}
//3. 데이터 후처리
RPM = data_process(count, tmp) / 4; Serial.println("RPM");
Serial.println(RPM);
break;
case 0x0D:
count = 1;
//2. count만큼 데이터를 자르고 저장 tmp배열에 임시 저장 for (int i = 0; i < count; i++) {
tmp[i] = diag.Data[i];
}
//3. 데이터 후처리
V = data_process(count, tmp); Serial.println("차량 속력");
Serial.println(V);
break;
case 0x9D:
count = 1;
//2. count만큼 데이터를 자르고 저장 tmp배열에 임시 저장 for (int i = 0; i < count; i++) {
tmp[i] = diag.Data[i];
}
//3. 데이터 후처리
Fuel_level = data_process(count, tmp); Serial.println("연료 잔량");
Serial.println(Fuel_level);
break;
case 0xA6:
count = 4;
//2. count만큼 데이터를 자르고 저장 tmp배열에 임시 저장 for (int i = 0; i < count; i++) {
tmp[i] = diag.Data[i];
}
//3. 데이터 후처리
D = data_process(count, tmp) / 10; Serial.println("총 주행거리");
Serial.println(D);
break;
default:
Serial.println("미구현");
break;
}
}
Serial.print("OBD code : "); Serial.print(pid); Serial.println(" end"); Serial.println("");
delay(1000);
}
}void UDS_receiver(void) {
int num = 0;
uint8_t pid = 0x00; //pid 의미없음 struct Session_t diag;
uint16_t retval = 0;
Serial.println(F("Diag Session"));
for (int i = 0; i < 8; i++) {
uint16_t rx_id_array[] = {0x7E8, 0x7E9, 0x7EA, 0x7EB, 0x7EC, 0x7ED, 0x7EE, 0x7EF}; diag.tx_id = 0x7DF; //0x7E0, 0x7DF
diag.rx_id = rx_id_array[i];
Serial.print("tx_id : "); Serial.println(diag.tx_id);
Serial.print("rx_id : "); Serial.println(diag.rx_id); //diag.tx_id = 0x7E0;
//diag.rx_id = 0x7E8;
diag.sid = OBD_MODE_READ_DTC;
diag.Data = &pid; | //진단 데이터 수신

- 19 -
diag.len = 0; | // before 1
if (retval = uds.Session(&diag))
{
Serial.print(F("UDS Session Error ")); Serial.print(retval); Serial.print(F(" NRC ")); Serial.println(retval, HEX);
}
else
{
Serial.println(F("Established with ")); uds.print_buffer(diag.Data, diag.len);
Serial.print("Length : "); Serial.println(diag.len);
}
Serial.print("UDS code"); Serial.print(num); Serial.println(" end..."); delay(1000);
}
}long data_process(int count, uint8_t *array_pointer) {
long result = 0;
//3. 데이터 후처리 시작
if (count != 1) //0,2,4,8씩 제곱
{
if (count == 2) //0~2
{
result = tmp[0] * pow(16, 2) + tmp[1]; //Serial.print("count is 2 : "); Serial.println(result); }
else if (count == 3) //0~4
{
result = tmp[0] * pow(16, 4) + tmp[1] * pow(16, 2) + tmp[2]; //Serial.print("count is 3 : "); Serial.println(result);
}
else if (count == 4) //0~8
{
result = tmp[0] * pow(16, 8) + tmp[1] * pow(16, 4) + tmp[2] * pow(16, 2) + tmp[3]; //Serial.print("count is 4 : "); Serial.println(result);
}
}
else {
result = tmp[0];
//Serial.print("count is 1 : "); Serial.println(tmp[0]);
}
return result;
}void mqtt_trans(int IGN, int RPM, int D, int V, int Eng_temp, int Fuel_level) { if (!client.connected()) {
reconnect();
}
client.loop();
unsigned long now = millis();
if (now - lastMsg > 500) {
lastMsg = now;
packet = String(IGN)+" "+String(RPM)+" "+String(D)+" "+String(V)+" "+String(Eng_temp)+" "+String(Fuel_level); packet.toCharArray(msg, 50);
Serial.print("Publish message: ");
Serial.println(msg);
client.publish("Env_car", msg);
}
}

## *CAR Translator_실제 차 통신에 쓰이는 코드

# include <esp32_can.h>

# include <iso-tp-esp32.h>

# include <uds-esp32.h>

# include <WiFi.h>

# include <PubSubClient.h>

- 20 -

# define MSG_BUFFER_SIZE (50) # define BUILTIN_LED 25

ESP32_CAN CAN0;
IsoTp isotp(&CAN0);
UDS uds(&isotp);
struct Session_t session;
char msg[MSG_BUFFER_SIZE];
const char* ssid = "Hong";
const char* password = "123456789q"; const char* mqtt_server = "180.71.2.76"; uint8_t tmp[] = {};
String packet;
long lastMsg = 0;
// 웹에 나타나는 정보 변수 초기화
int IGN = 0;
int RPM = 0;
int D = 0;
int V = 0;
int Eng_temp = 0;
int Fuel_level = 0;
int Eng_runtime = 0;
int Fuel_tank_level_input = 0; int engine_load = 0;
int DTC_on_D = 0;
int DTC_clr_D = 0;
int engine_oil = 0;
int relative_accel_pedle = 0; WiFiClient esp_client;
PubSubClient client(esp_client); // 사용되는 함수 초기화
void displayWifistatus(void);
void OBD2_receiver(uint8_t pid);
void UDS_receiver(void);
long data_process(int count, uint8_t *array_pointer);
void mqtt_trans(int IGN, int (RPM), double D, int V, float Eng_temp, int Fuel_level); void callback(char* topic, byte* payload, unsigned int length);
void reconnect();
void setup() {
// put your setup code here, to run once: Serial.begin(115200);
Serial.println();
//1. wifi연결
WiFi.begin(ssid, password); Serial.println("Connecting");
while (WiFi.status() != WL_CONNECTED) {
displayWifistatus();
delay(500);
}
displayWifistatus();
Serial.println();
Serial.print("Conncected, IP address: "); Serial.println(WiFi.localIP()); Serial.print("Gateway IP: "); Serial.println(WiFi.gatewayIP()); Serial.print("RSSI: ");
Serial.println(WiFi.RSSI());
//2. Mqtt 연결
pinMode(BUILTIN_LED, OUTPUT); client.setServer(mqtt_server, 1883);
client.setCallback(callback);
//3. CAN 연결
if (CAN0.begin(16, 17, CAN_500KBPS) == CAN_OK) { | //25,50,100,125,250,500,800,1000
Serial.println("ESP32 CAN Initialized Successfully!");

- 21 -

} else {
Serial.println("Error Initializing ESP32 CAN..."); return;
}
delay(5000);
}void loop() {
uint8_t pid[] = {0x04, 0x05, 0x0C, 0x0D, 0x11, 0x1F, 0x21, 0x2F, 0x31, 0x5A, 0x5C}; uint8_t uds_id[] = {};
//1. OBD2로 Data receive
for (int i = 0; i < sizeof(pid) / sizeof(uint8_t) ; i++)
OBD2_receiver(pid[i]);
//2. UDS로 Data receive
UDS_receiver();
//3. 시동이 켜져있다면
if (IGN == 1);
mqtt_trans(IGN, RPM, D, V, Eng_temp, Fuel_level); //4. MQTT를 이용해 서버로 전송 }void displayWifistatus(void) {
Serial.print("ESP WiFi connection status: ");
switch (WiFi.status()) {
case 0:
Serial.println("WL_IDLE_STATUS"); break;
case 1:
Serial.println("WL_NO_SSID_AVAIL"); break;
case 3:
Serial.println("WL_CONNECTED"); break;
case 4:
Serial.println("WL_CONNECT_FAILED"); break;
case 6:
Serial.println("WL_DISCONNECTED"); break;
default:
Serial.println("Unknown status");
}
}void callback(char* topic, byte* payload, unsigned int length) { Serial.print("Message arrived [");
Serial.print(topic);
Serial.print("] ");
for (int i = 0; i < length; i++) { Serial.print((char)payload[i]);
}
Serial.println();
// Switch on the LED if an 1 was received as first character
if ((char)payload[0] == '1') {
digitalWrite(BUILTIN_LED, LOW); // Turn the LED on (Note that LOW is the voltage level // but actually the LED is on; this is because

// it is active low on the ESP-01)
} else {
digitalWrite(BUILTIN_LED, HIGH); // Turn the LED off by making the voltage HIGH }
}void reconnect() {
// Loop until we're reconnected
while (!client.connected()) { Serial.print("Attempting MQTT connection..."); // Create a random client ID
String clientId = "ESP8266Client-";
clientId += String(random(0xffff), HEX);
// Attempt to connect
if (client.connect(clientId.c_str())) { Serial.println("connected");
// Once connected, publish an announcement...

- 22 -

client.publish("start", "Connected Mqtt..."); // ... and resubscribe
client.subscribe("inTopic");
} else {
Serial.print("failed, rc="); Serial.print(client.state()); Serial.println(" try again in 5 seconds"); // Wait 5 seconds before retrying delay(5000);
}
}
}void OBD2_receiver(uint8_t pid) { int num = 0;
int count = 0;
long f_result = 0;
struct Session_t diag;
uint16_t retval = 0;
Serial.print(F("OBD2 request PIDs: ")); Serial.println(pid);
for (int i = 0; i < 1; i++) {
uint16_t rx_id_array[] = {0x7E9, 0x7E9};
diag.tx_id = 0x7DF; //0x7E0, 0x7DF -> 7DF였으면 원래 응답이 와야하는대 안됐음. // | 예제 하나 줄테니 실제 차량에서 진행해보자. //

diag.rx_id = rx_id_array[i];
Serial.print("tx_id : "); Serial.println(diag.tx_id); Serial.print("rx_id : "); Serial.println(diag.rx_id); //diag.rx_id = 0x7E8;
diag.sid = OBD_MODE_SHOW_CURRENT_DATA; diag.Data = &pid;
diag.len = 1;
if (retval = uds.Session(&diag))
{
Serial.print(F("OBD2 Error ")); Serial.print(retval);
Serial.print(F(" NRC "));
Serial.println(retval, HEX);
}
else
{
//0x1F, 0x05, 0x0C, 0x0D, 0x9D, 0xA6 //pid별 최대 바이트로 자르는 코드 시작
//diag.Data는 한 프레임에 8비트씩 담겨진다. /*

Serial.println(diag.Data[0]);///A 8bit Serial.println(diag.Data[1]);///B 8bit Serial.println(diag.Data[2]);///C 8bit Serial.println(diag.Data[3]);///D 8bit
*/
//1.각 pid별로 몇바이트인지 count변수에 저장 switch (pid) {
case 0x04:
engine_load = 100*diag.Data[0]/255; Serial.print("엔진 부하 : ");
Serial.println(engine_load);
break;
case 0x05:
Eng_temp = diag.Data[0]-40; Serial.print("엔진 온도 : ");
Serial.println(Eng_temp);
break;
case 0x0C:
RPM = ((diag.Data[0]*pow(2,8)) + diag.Data[1])/4; Serial.print("RPM : ");
Serial.println(RPM);

- 23 -

break;
case 0x0D:
V = diag.Data[0];
Serial.print("차량 속력 : ");
Serial.println(V);
break;
case 0x1F: //IGN 체크
Eng_runtime = (diag.Data[0]*pow(2,8)) + diag.Data[1]; Serial.print("엔진이 켜진 이후부터의 주행 시간 : "); Serial.println(Eng_runtime);
if(Eng_runtime > 0)
IGN = 1;
else
IGN = 0;
break;
case 0x21:
DTC_on_D = (diag.Data[0]*pow(2,8)) + diag.Data[1]; Serial.print("DTC_on_D : "); Serial.println(DTC_on_D);
break;
case 0x2F:
Fuel_tank_level_input = 100*diag.Data[0]/255; Serial.print("Fuel_tank_level_input : "); Serial.println(Fuel_tank_level_input);
break;
case 0x31:
DTC_clr_D = (diag.Data[0]*pow(2,8)) + diag.Data[1]; Serial.print("DTC_clr_D : "); Serial.println(DTC_clr_D);
break;
case 0x5A:
relative_accel_pedle = 100*diag.Data[0]/255; Serial.print("relative_accel_pedle : "); Serial.println(relative_accel_pedle);
break;
case 0x5C:
engine_oil = diag.Data[0]-40; Serial.print("engine_oil : "); Serial.println(engine_oil); break;
case 0x9D:
Fuel_level = 0;
Serial.print("연료 잔량 : ");
Serial.println(Fuel_level);
break;
case 0xA6:
D = (diag.Data[0]*pow(2,24)+diag.Data[1]*pow(2,16)+diag.Data[2]*pow(2,8)+diag.Data[3])/10; Serial.print("총 주행거리");
Serial.println(D);
break;
default:
Serial.println("미구현");
break;
}
}
Serial.print("OBD code : "); Serial.print(pid); Serial.println(" end"); Serial.println("");
delay(1000);
}
}void UDS_receiver(void) {
int num = 0;
uint8_t pid = 0x00; //pid 의미없음 struct Session_t diag;
uint16_t retval = 0;

- 24 -

Serial.println(F("Diag Session"));
for (int i = 0; i < 8; i++) {
uint16_t rx_id_array[] = {0x7E8, 0x7E9, 0x7EA, 0x7EB, 0x7EC, 0x7ED, 0x7EE, 0x7EF}; diag.tx_id = 0x7DF; //0x7E0, 0x7DF
diag.rx_id = rx_id_array[i];
Serial.print("tx_id : "); Serial.println(diag.tx_id);
Serial.print("rx_id : "); Serial.println(diag.rx_id); //diag.tx_id = 0x7E0;
//diag.rx_id = 0x7E8;
diag.sid = OBD_MODE_READ_DTC;
diag.Data = &pid; | //진단 데이터 수신
diag.len = 0; | // before 1
if (retval = uds.Session(&diag))
{
Serial.print(F("UDS Session Error ")); Serial.print(retval); Serial.print(F(" NRC ")); Serial.println(retval, HEX);
}
else
{
Serial.println(F("Established with ")); uds.print_buffer(diag.Data, diag.len);
Serial.print("Length : "); Serial.println(diag.len);
}
Serial.print("UDS code"); Serial.print(num); Serial.println(" end..."); delay(1000);
}
}void mqtt_trans(int IGN, int RPM, int D, int V, int Eng_temp, int Fuel_level) { if (!client.connected()) {
reconnect();
}
client.loop();
unsigned long now = millis();
if (now - lastMsg > 500) {
lastMsg = now;
packet = String(IGN)+" "+String(RPM)+" "+String(D)+" "+String(V)+" "+String(Eng_temp)+" "+String(Fuel_level); packet.toCharArray(msg, 50);
Serial.print("Publish message: ");
Serial.println(msg);
client.publish("Env_car", msg);
}

}

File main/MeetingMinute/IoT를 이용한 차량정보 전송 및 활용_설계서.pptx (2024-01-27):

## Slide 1

한이음 ▶ 프로그램 설계서

내가 기획한 ICT가
세상을 바꾼다면?

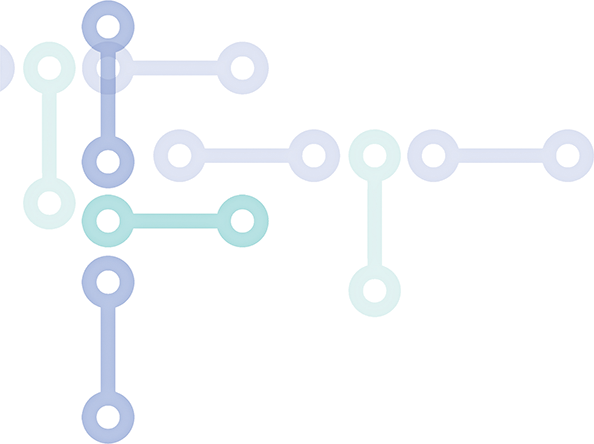
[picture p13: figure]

SW개발/HW제작 설계서

프로젝트 명 : [20_HF001] IoT를 이용한 차량정보 전송 및 활용

2020. 07. 30
(CAN) – 정홍석, 강혜인, 우창민
Mentor 최무석

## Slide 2

| 시장/기술 동향 분석

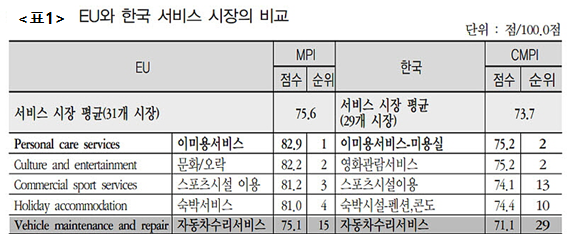
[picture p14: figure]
EMB00000a184486

- 한국자동차 기술신문의 자동차 서비스시장과 변화대응에 따르면 한국의 자동차 수리서비스의 CMPI점수는 71.1이고 29위로 CMPI의 평균값인 73.7에도 미치지 못함.
- 이는 한국 뿐만이 아니라 유럽도 같은 현상을 보이며, EU 자동차수리서비스가 서비스분야 15위로 중위권 평가를 받고 있음.
- 따라서, 자동차 수리 서비스의 문제점을 느끼고 있는 것은 한국뿐 만이 아니라는 걸 알 수 있음.

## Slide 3

| 시장/기술 동향 분석

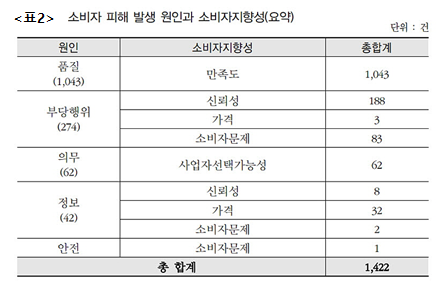
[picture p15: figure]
EMB00000a184489

- 2015년 한국소비원에 접수된 자동차 서비스 불만신고들을 정리한 표를 보면 불만의 86.6%는 사업자가 자신의 일을 제대로 하지 않았기 때문에 생긴 것으로 나타남.
- 이는 자동차 서비스 센터에 대한 소비자들의 신뢰성이 떨어져 있음을 나타냄.
- 따라서, 자동차 수리 서비스의 문제점을 해결하기 위해 소비자들은 자신들의 차의 정보에 관심이 증대될 것 이다.

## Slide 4

시장/기술 동향 분석

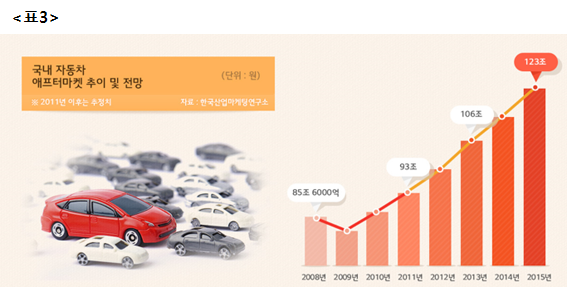
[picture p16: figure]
EMB00000a1844a2
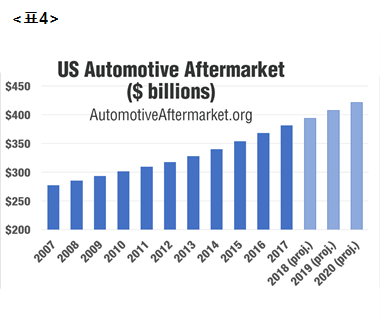
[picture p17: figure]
EMB00000a1844a5

- 해외에선 에프터 마켓이 활성화 되어 소비자가 직접 부품을 구매하여 자동차를 관리하는 추세.
- 국내 자동차 에프터 마켓 시장의 규모는 이미 87조원대를 기록했으며, 현재 100조원대를 뛰어넘음.
- 미국의 에프터 마켓 시장은 2017년에 약 414조원대를 기록했으며, 2020년에는 약 473조의 크기의 시장을 가질 것이라고 예상됨
따라서, 저희 작품은 타이어의 교체주기와 자동차의 부품시기를 예측하고 알려주는 기능을 가지고 있어 자동차 에프터 마켓을 이용하여 직접 수리하는 소비자들에게 필수적인 장비가 될 것이라고 생각됨.

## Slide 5

| 요구사항 정의서_1

요구사항 ID | 요구사항명 | 기능 ID | 기능명 | 세부사항 | 예외사항
A01 | 차량 데이터 값 | A01_B01 | RPM | RPM 값 표현 | X
| | A01_B02 | Speed | Speed 값 표현 | X
| | A01_B03 | ODO | ODO 값 표현 | X
| | A01_B04 | Engine Temperature | 엔진 냉각수 온도 값 표현 | X
A02 | 차량 데이터 그래프 | A02_B01 | RPM | RPM 그래프 표현 | X
| | A02_B02 | Speed | Speed 그래프 표현 | X
| | A02_B03 | ODO | ODO 그래프 표현 | X
| | A02_B04 | Engine Temperature | 엔진 냉각수 온도 그래프 표현 | X
A03 | 차량 부품 교체 정보 | A03_B01 ~ A03_B11 | 엔진오일, 오토미션오일, 파워 오일 등 | 교체 장비명과 교체 위험도를 표현 | X
A04 | 고장 정보 | A04_B01 ~ A04_B04 | 파워트레인(P) 통신(U) 섀시 시스템(C) 바디 시스템(B) | 고장코드, 고장 위험도, 고장 내용 상세, 해결방법 표현 | X

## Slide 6

| 요구사항 정의서_2

요구사항 ID | 요구사항명 | 기능 ID | 기능명 | 세부사항 | 예외사항
A05 | CAN/ UDS 통신 | A05_B01 | SID | 차량 데이터를 받기 위한 service ID | X
| | A05_B02 | PID | 차량 데이터를 받기 위한 parameter ID | X
A06 | 인터넷 통신 | A06_B01 | HTTP | WIFI 서버와 데이터 교환 | X
| | A06_B02 | PHP | WIFI 서버와 데이터 교환 | X
| | A06_B03 | MQTT | WIFI 서버와 데이터 교환 | X

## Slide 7

| 서비스 구성도 - 서비스 시나리오

MAIN

그래프 통계

사용자

WEB SERVER

차량부품
교체정보

고장
정보

- Main
-RPM, Speed, ODO, Engine Temperature
- 그래프 통계
-RPM, Speed, ODO, Engine Temperature
- 차량 부품 교체 정보
- 엔진오일, 와이퍼, 냉각수 등
- 고장정보
- 고장코드, 고장위험도, 고장 내용, 해결방법

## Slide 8

| 서비스 구성도 - 서비스 시나리오

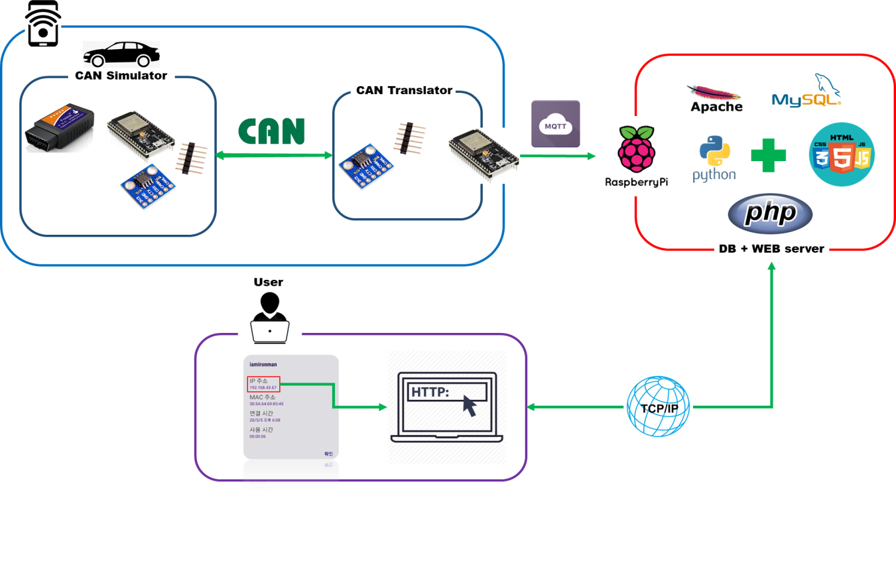
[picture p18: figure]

Back-end
- CAN 통신: 차량에서 데이터 수신
- TCP/IP 통신: 수신한 데이터 DB에 송신 및 저장 후 가공할 데이터는 파이썬을 통해 가공하고 일반 데이터는 그대로 WEBSERVER에 송신
Front-end
- 초기 데이터 요청: 부품 교체 시기
- 데이터 전달
- 데이터를 그래프화해서 전달

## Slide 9

| 서비스 구성도 - 서비스 시나리오

2. 차량 데이터
송신

1. 차량 데이터
요청

3. 차량 데이터
송신

4. 데이터
가공/제공

1. 차량 데이터 요청
2. 차량 데이터 송신(Simulator-> Translator)
3. 차량데이터 송신(Translator->DB)
4. 데이터 가공/제공(파이썬을 통해 데이터 가공/웹 서버로 가공한 데이터 제공)

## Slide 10

| 메뉴 구성도

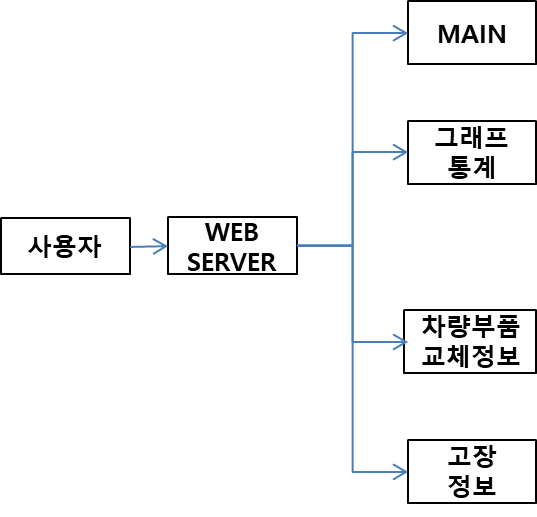
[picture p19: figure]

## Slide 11

| 화면 설계서

| 기능 명 | Main
| 기능설명 | 웹의 첫 화면, 데이터 수치를 볼 수 있음
| 처리내용 | -RPM, Speed, ODO, Engine Temperature 값들을 db에서 받아와서 화면에 출력
| 비고 | 없음
| 요구사항 명 | 데이터 값 표현

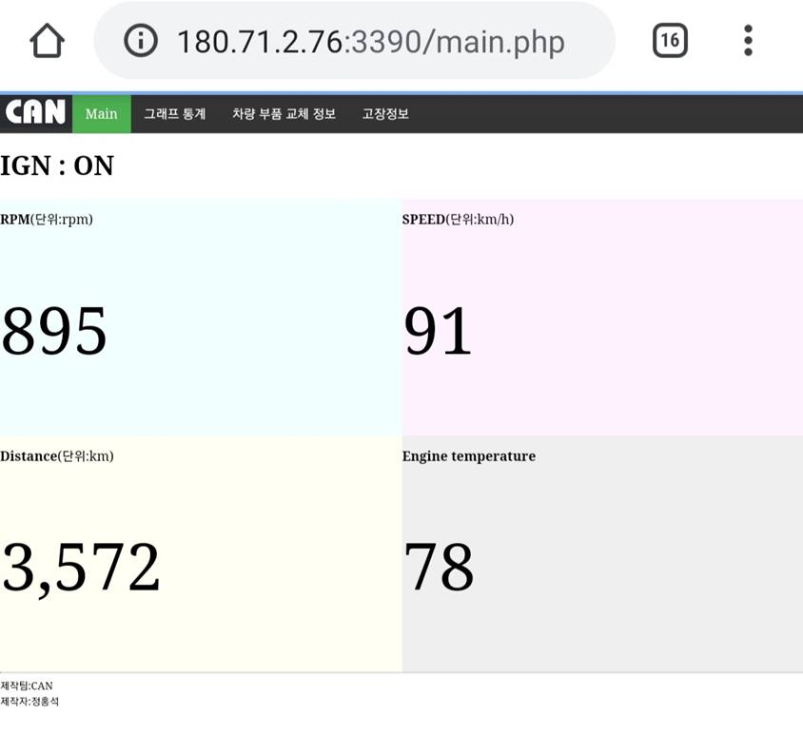
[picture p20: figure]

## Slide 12

| 화면 설계서

| 기능 명 | 그래프 통계
| 기능설명 | 웹의 두 번째 화면, 데이터를 시각화한 그래프를 볼 수 있음
| 처리내용 | -RPM, Speed, ODO, Engine Temperature 값들을 DB에서 파이썬으로 가공한 후 받아와 그래프를 화면에 출력
| 비고 | 없음
| 요구사항 명 | 그래프 표현

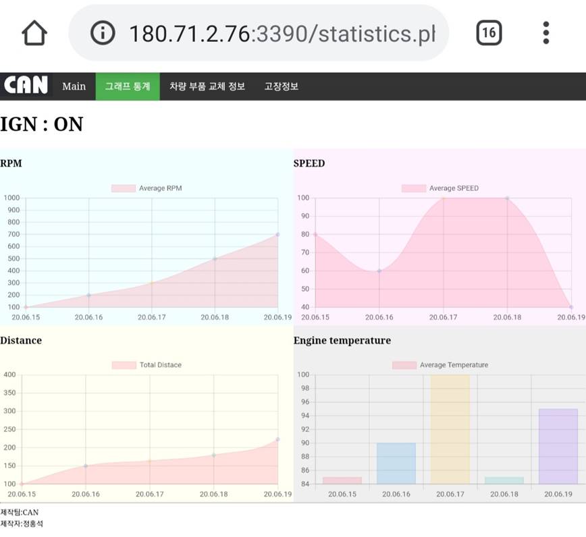
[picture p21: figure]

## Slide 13

| 화면 설계서

| 기능 명 | 차량 부품 교체 정보
| 기능설명 | 웹의 세 번째 화면, 부품 교체 정보를 볼 수 있음
| 처리내용 | 차량 부품 교체 장비명 - 엔진오일, 와이퍼, 냉각수 등 교체 위험도 - High, Middle, Low
| 비고 | 없음
| 요구사항 명 | 차량 부품 교체 정보 표현

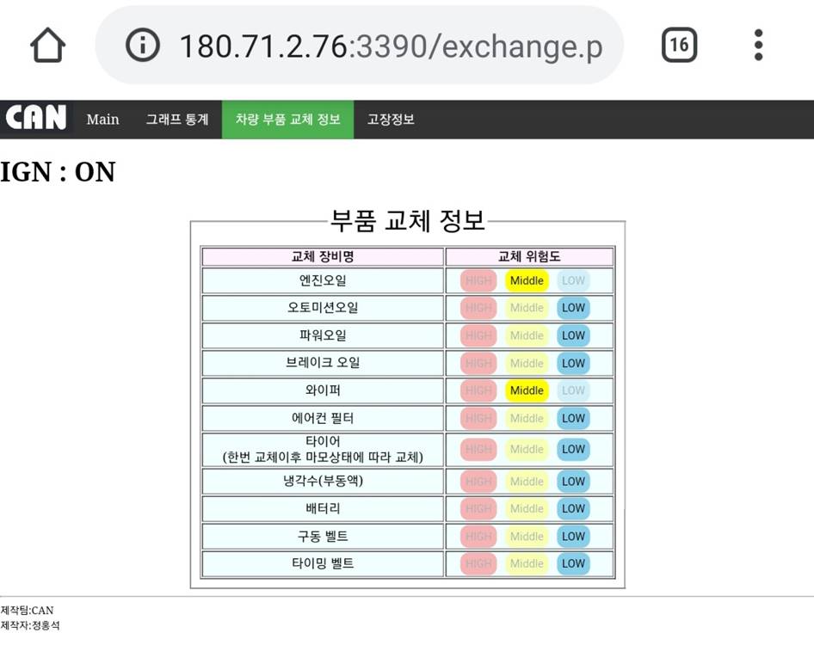
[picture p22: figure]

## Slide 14

| 화면 설계서

| 기능 명 | 고장정보
| 기능설명 | 웹의 네 번째 화면, 고장 코드를 볼 수 있음
| 처리내용 | 고장코드 고장위험도: High, Middle, Low 고장 내용 해결방법
| 비고 | 없음
| 요구사항 명 | 데이터 값 표현

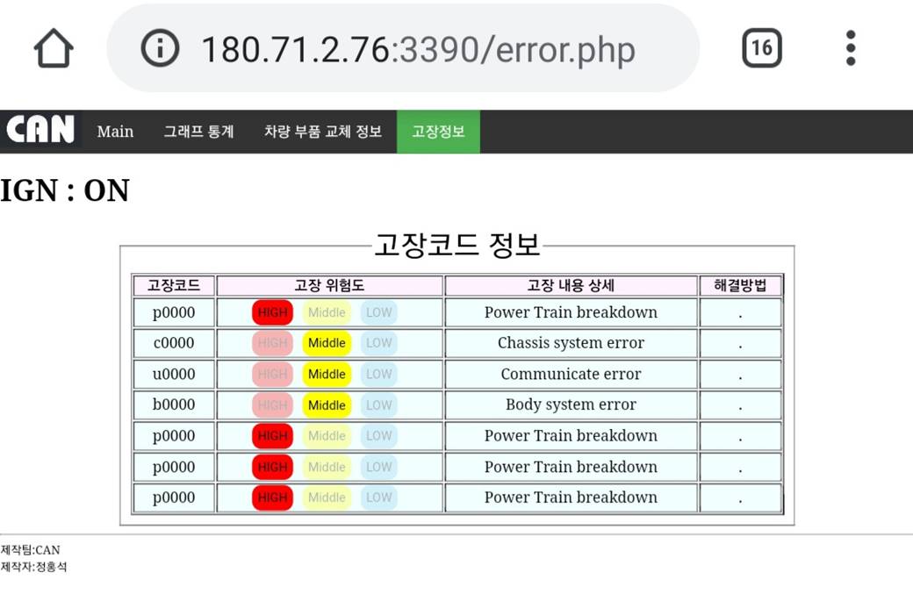
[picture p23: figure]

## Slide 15

| 엔티티관계도 - ERD

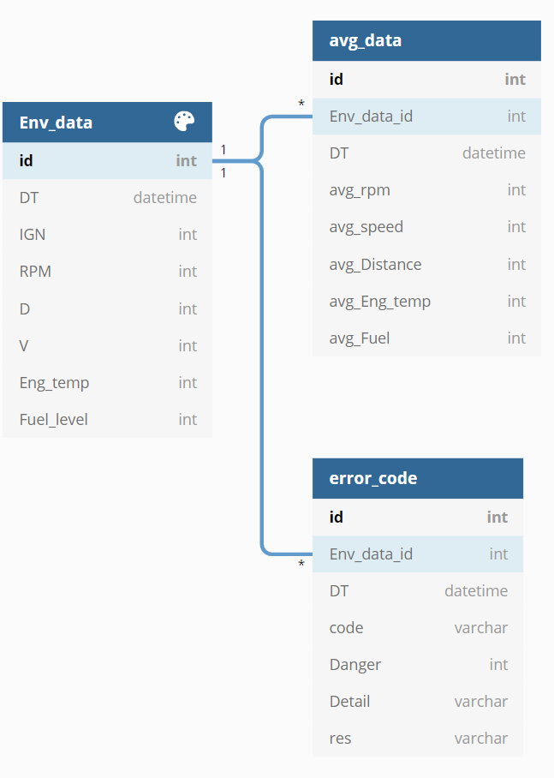
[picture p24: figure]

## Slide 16

| 기능 처리도(기능 흐름도)

실무 산출물 형식

프로그램 ID | ESP32_1 | 프로그램 명 | OBD2_ECU_Simulator.ino | 작성일 | 2020.07.30 | Page | 1/8
개요 | 차량과 OBD 및 UDS 통신을 수행하여 실시간으로 차량 운행 데이터를 수집하고 DB에 전송하는 프로그램 | | | | | 작성자 | 정홍석

기능 흐름도

<차량 시뮬레이터>

N

프로그램 실행

CAN 초기화

고장코드 값
임시서장

IGN ON
확인

임시저장 값 전송

Y

IGN ON
확인

Y

RPM, 주행거리, 차속, 연료잔량 값 Set

Y

RPM, 주행거리, 차속, 연료잔량 임시저장

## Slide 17

| 기능 처리도(기능 흐름도)

실무 산출물 형식

프로그램 ID | ESP32_2 | 프로그램 명 | hanium_from_esp32_DB.ino | 작성일 | 2020.07.30 | Page | 2/8
개요 | 차량과 OBD 및 UDS 통신을 수행하여 실시간으로 차량 운행 데이터를 수집하고 DB에 전송하는 프로그램 | | | | | 작성자 | 정홍석

기능 흐름도

<차량 운행 데이터 수집 및 저장 연계도>

N

프로그램 실행

CAN 초기화

Y

데이터 수신

WIFI 연결

Y

데이터 파싱

DB로 데이터 전송

차량 데이터 DB

IGN ON
확인

데이터 요청

Y

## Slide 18

| 기능 처리도(기능 흐름도)

실무 산출물 형식

프로그램 ID | Rasp_server_1 | 프로그램 명 | Main.php | 작성일 | 2020.07.30 | Page | 3/8
개요 | 수집된 데이터를 DB에서 가져와 웹상에 표시해주는 프로그램 | | | | | 작성자 | 정홍석

기능 흐름도

<Main.php 기능 흐름도>

프로그램 실행

DB 접속

데이터 조회

RPM, SPEED, Distance, Engine temperature 데이터 조회

Refresh

조회 결과
변수에 할당

데이터 표시

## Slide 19

| 기능 처리도(기능 흐름도)

실무 산출물 형식

프로그램 ID | Rasp_server_2 | 프로그램 명 | statistics.php | 작성일 | 2020.07.30 | Page | 4/8
개요 | 일평균 데이터를 DB에서 가져와 웹상에 그래프로 표시해주는 프로그램 | | | | | 작성자 | 정홍석

기능 흐름도

<statistics.php 기능 흐름도>

프로그램 실행

DB 접속

데이터 조회

RPM, SPEED, Distance, Engine temperature 의 일 평균 데이터 조회

Refresh

조회 결과
변수에 할당

Chart.js로 데이터 표시

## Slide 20

| 기능 처리도(기능 흐름도)

실무 산출물 형식

프로그램 ID | Rasp_server_3 | 프로그램 명 | exchange.php | 작성일 | 2020.07.30 | Page | 5/8
개요 | 차량의 총 운행 거리에 따른 소모품 교체 알림을 시각적으로 보여주기 위한 프로그램 | | | | | 작성자 | 정홍석

기능 흐름도

<exchange.php 기능 흐름도>

프로그램 실행

DB 접속

데이터 조회

Distance 데이터 조회

Refresh

조회 결과
변수에 할당

Distance에 따른
소모품 교체 알림 표시

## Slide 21

| 기능 처리도(기능 흐름도)

실무 산출물 형식

프로그램 ID | Rasp_server_4 | 프로그램 명 | error.php | 작성일 | 2020.07.30 | Page | 6/8
개요 | UDS 프로토콜을 통해 DB에 저장된 고장코드 정보를 웹에 표시하는 프로그램 | | | | | 작성자 | 정홍석

기능 흐름도

<error.php 기능 흐름도>

프로그램 실행

DB 접속

데이터 조회

Error Code 데이터 조회

Refresh

조회 결과
변수에 할당

고장코드에 따른
상세 내역 표시

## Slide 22

| 기능 처리도(기능 흐름도)

실무 산출물 형식

프로그램 ID | Rasp_server_5 | 프로그램 명 | dbtest.php | 작성일 | 2020.07.30 | Page | 7/8
개요 | Esp32에서 전송되는 차량 운행 데이터를 DB에 저장 | | | | | 작성자 | 정홍석

기능 흐름도

<dbtest.php 기능 흐름도>

프로그램 실행

DB 접속

차량 운행 데이터
수신 대기

차량 운행 데이터 수신 및 파싱

SQL문으로 DB에 저장

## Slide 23

| 알고리즘 명세서_Simulator

1. 값들을 초기화
2. CAN 통신연결
3. 엔진이 켜져 있는지 체크
4. 가변저항을 통해 차량 obd 값 세팅&저장
5. 스위치를 통해 DTC 값 세팅&저장
6. Translator 측으로부터 요청이 왔는지 체크하고 안 왔으면 1번으로 돌아가고 왔으면 다음
7. SID= 1(Show Current Data)
SID= 3(Read DTC)
8. SID=1이면 OBD2 값들을 전송
9. SID=3이면 DTC 값들을 전송

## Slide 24

| 알고리즘 명세서_Translator

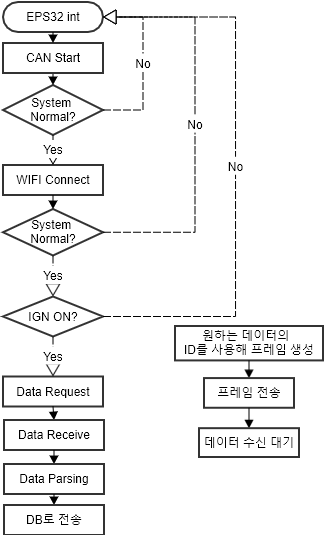
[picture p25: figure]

1. 값들을 초기화
2. CAN 통신이 가능한지 체크
3. 시스템 정상인지?
4. WIFI 연결
5. 시스템 정상인지?
6. 엔진이 켜져 있는지?
7. DATA 요청-1)원하는 데이터 ID 프레임화
2)프레임 전송
3)데이터 수신 대기
8. 데이터 수신
9. 데이터 파싱
10. DB로 전송

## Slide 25

| 알고리즘 명세서_WEB

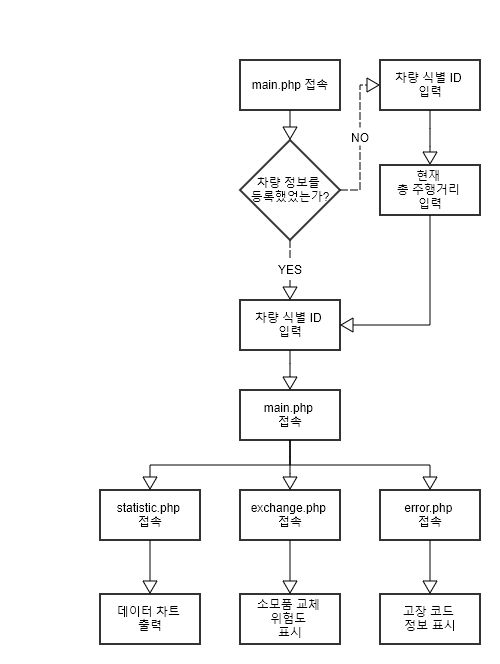
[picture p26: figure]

1. 첫 페이지인 main에 접속
2. 차량 정보 등록을 했었는지 체크
2-no. 차량 식별 ID 입력->현재 총 주행거리
입력
3. 차량 식별 ID 입력
4. 차량 식별 ID를 통해 사용자의 정보를
main에 실시간 출력
4-1. 통계 페이지 접속
5-1. 데이터 차트 출력
4-2. 소모품 교체 페이지 접속
5-2. 소모품 교체 위험도 표시
4-3. 고장 코드 페이지 접속
5-3. 고장 코드 정보 표시

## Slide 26

| 하드웨어 설계도

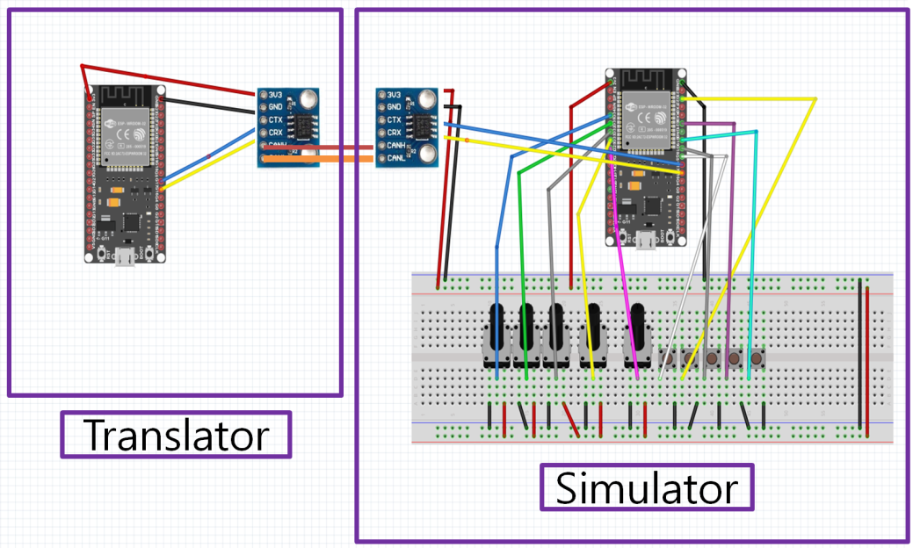
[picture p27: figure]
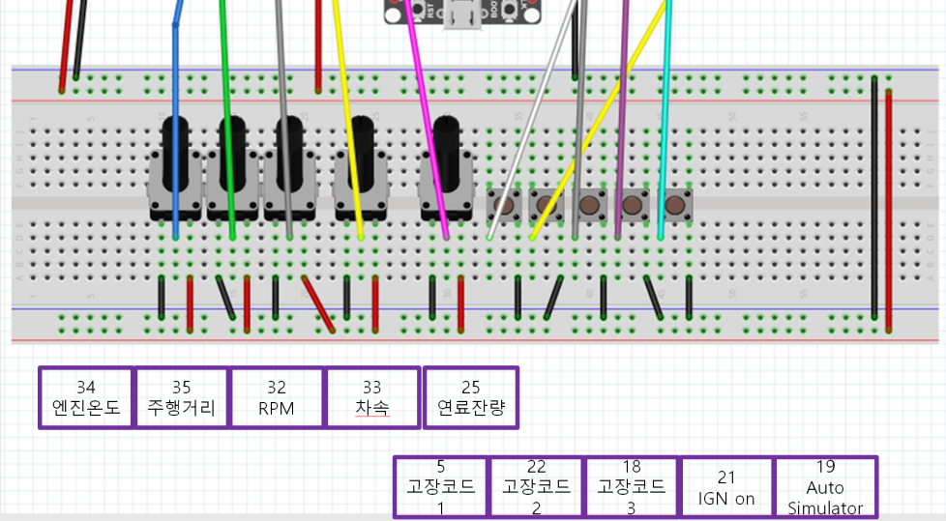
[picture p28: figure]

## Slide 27

| 프로그램 - 목록

기능 분류 | 기능번호 | 기능 명
Sav | Sav-01 | Php에서 차량 운행 데이터 DB에 전송
| Sav-02 | Python을 이용하여 가공된 데이터 DB에 전송
Cmc | Cmc-01 | ESP32에서 OBD2, UDS를 통한 데이터 송수신
| Cmc-02 | ESP32에서 WIFI 연결 및 데이터 전송
Calc | Calc-01 | 각 데이터 일 평균 계산
| Calc-02 | 급가속, 급감속 계산
Web | Web-01 | 데이터 웹에 표시
| Web-02 | 데이터를 그래프로 웹에 표시
| Web-03 | 차량 부품 교체 정보 표시
| Web-04 | 차량 고장 정보 표시

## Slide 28

| 테이블 정의서 - ERD


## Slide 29

| 테이블 정의서 - ERD


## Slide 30

| 테이블 정의서 - ERD


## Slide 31

| 테이블 정의서 - ERD


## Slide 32

| 핵심소스코드(1)


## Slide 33

| 핵심소스코드(2)


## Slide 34

| 핵심소스코드(3)


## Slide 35

| 참조- 개발 환경 및 설명

구분 | | 항목 | 적용내역
S/W 개발환경 | CAN Simulator/ CAN Translator 개발 | Arduino IDE (1.8.9) | 차량 역할을 할 CAN Simulator와 차량에서 Data를 받아오는 CAN Translator 개발
| 서버 애플리케이션 개발 | PHP(5.3.3) | 서버 관리자 웹 페이지 처리 모듈 작성
| | MySQL(5.1.73) | 차량 데이터를 저장, 관리하는 데이터베이스
| | Apache(1.7.1) | 관리자 웹 페이지를 구동하는 웹 서버
| | 서버 운영체제 | 리눅스 Rasbian OS
| | Putty | Rasbian OS 원격 접속용 툴
H/W 구성장비 | 디바이스 | 스마트폰 (안드로이드, 아이폰) | 사용자에게 서비스를 직접적으로 제공하는 End Device
| | ESP 32 | CAN Simulator, CAN Translator 제작에 필요한 MCU
| 통신 | WIFI | ESP32와 Rasberry Pi 4 통신
| | 무선 랜 어댑터 | 스마트폰과 웹서버 통신
| 서버 | Rasberry Pi 4 | 웹 호스팅 및 DB 정보를 변환해 다시 저장해주는 서버

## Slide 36

내가 기획한 ICT가
세상을 바꾼다면?

Thank you


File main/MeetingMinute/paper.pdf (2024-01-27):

## IoT를 이용한 차량정보 전송 및 활용 설계 및 구현

### Transmission and Utilization of Vehicle Information Using IoT

우창민(17019049), 정홍석(15051044), 강혜인(16039002)

{changmin159 wjdghd1227, dls1358}@naver.com

지도교수 : 손수국

Ⅰ. 작품 개요

자동차 애프터 마켓 시장은 관련 기술의 진전과 함께 비약적인 발전을 거듭하여 여러 자 동차 애프터 마켓 상품이 개발됨과 동시에 가파른 성장세를 보이고 있다. 다양한 기술과 차량의 점검과 관리를 위해 차량운전자와 정비사가 동시동소에 있어야 하는 제약을 해결하 기 위해 본 논문에서는 IoT를 이용한 차량정보 전송 및 활용 기술을 소개하고자 한다. 본 기술은 S/W로 CAN통신, WEB 서버, DB, MQTT, WIFI 등의 기술을 사용하였고, H/W로 ESP 32, Rasberry Pi 4를 사용하고 있다. Ⅱ. 작품 목적 및 필요성

가. 에프터 마켓을 이용하는 운전자를 위한 차량관리 서비스

소비자들은 에프터 마켓을 활용하여 직접 정비하고, 부품을 구매할 수 있다. 유럽과 미국 등에서는 이미 에프터 마켓이 활성화 되어 소비자가 직접 부품을 구매하여 자동차를 관리 하고 있고 시장 규모도 2020년 약 504조원이다. 우리나라의 자동차 에프터 마켓 시장은 한 해 약 6조원씩 성장하며 가파른 성장세를 보이고 있다. 이처럼, 사람들의 차량에 대한 관심 은 증가하고 있다. 하지만 차량의 점검 및 관리에는 여전히 정비소를 방문한다. 이는, 차량 운전자와 정비책임자가 모두 동일 시간, 장소에 있어야 하는 제약이 따른다. 이러한 공간 적, 시간적 제약에서 벗어나 운전자가 자신의 차량을 점검 및 관리 할 수 있는 IoT를 이용 한 차량정보 전송 및 활용 기술을 이용해 더 이상 정비소를 방문하지 않고도 차량정비가 가능한 서비스를 제작하였다. 따라서, 우리 작품은 타이어의 교체주기와 자동차의 부품시기 를 예측하고 알려주는 기능을 가지고 있어 자동차 에프터 마켓을 이용하여 직접 수리하는 소비자들에게 필수적인 장비가 될 것이라고 생각된다.


- 2 -

나. 정비사와 소비자의 커뮤니케이션을 용이하게 해주는 서비스

한국자동차 기술신문의 자동차 서비스시장과 변화대응에 따르면 한국의 자동차 수리서 비스 만족도를 나타내는 CMPI점수는 71.1이고 29위로 CMPI의 평균값인 73.7에도 미치 지 못하는 것을 알 수 있다. 이런 현상은 이는 한국 뿐만이 아니라 유럽도 같은 현상을 보이며, EU 자동차수리서비스가 서비스분야 15위로 중위권 평가를 받고 있다. 따라서 운 전자들에게 차량의 정보를 전송해 주고 이 데이터를 관리해 주어 자신에 차량정보에 관 한 정보를 알려주는 우리의 서비스를 이용한다면. 소비자에게 정비사와의 커뮤니케이션 을 용이하게 도와주는 중요한 매개체가 될 것이다. Ⅲ. 작품 특징 및 독창성

가. MQTT를 이용하여 WEB에서 차량 정보 관리

차량상태와 진단정보는 차량이 있는 장소에서 진단장비를 차량의 OBD 단자에 접속해야 만 얻을 수 있다. 따라서 차량운전자와 정비책임자가 모두 동일시간, 동일 장소에 존재해 야 하는 공간적, 시간적 제약에서 벗어나기 위해 차량상태와 진단정보를 MQTT를 이용 해서 원격으로 전송하여 운전자가 자신의 차량을 점검하고 부가 서비스를 이용하여 관리 가능하게 하였다. 기존 기술인 OBD2를 이용해서 차량상태를 진단 및 데이터 저장하였고 접근성에서 가장 뛰어난 수단인 WEB으로 수집된 데이터를 웹 페이지에서 시각적으로 표현하였다. 수집된 총 주행거리 데이터를 이용해 차량의 부품 교체 시기 예측하였다. Ⅳ. 작품 설계

가. 작품구성

본 시스템은 (사진 1)과 같이 구성되어 있다.

(사진 1) 시스템 구성도


- 3 -

(사진 4) 차량-ESP32 CAN 통신 결과
(사진 5) service 01-pid05 공식

ESP32는 클라이언트, 라즈베리파이는 DB 서버와 WEB 서버 역할을 한다. ESP32를 통 해 CAN을 구현하고, 이를 통해 차량으로부터 운행 데이터를 실시간으로 받는다. ESP32 는 전송 받은 데이터를 DB에 전달하기 적당한 형태로 전처리하고 MQTT를 이용해 broker 역할을 하는 라즈베리파이에게 전송한다. 라즈베리파이는 전달 받은 데이터를 DB 에 저장하고 이를 php를 이용해 데이터를 조회하며 javascript의 AJAX를 이용해 주기적 으로 정보를 갱신하고 새로운 데이터가 업데이트 될 때마다 웹 페이지의 일부를 갱신함 으로써 사용자가 실시간으로 차량의 운행 정보를 확인 할 수 있도록 한다. Ⅴ. 작품 구현

실제 차량에서 통신 테스트를 하기 전에 Simulator를 제작하여 잘 동작하는지 테스트를 실제 차량에서 ESP32와 OBD-II 통신 테스트를 진행했다. OBD-II 서비스1의 PID05번 을 이용해 CAN을 테스트한 결과 (사진 4)와 같이 CAN 통신을 통한 OBD-II 프로토콜 로 자동차의 엔진 냉각수온도와 5Fh 데이터 값을 원활하게 주고받는 것을 확인 할 수 있 다. 5Fh로 들어온 값은 service 01-pid 05의 공식인 A-40(사진 5)에 의해 실제 값은 55가 된다.

통신 딜레이를 최소화 하기위해 MQTT와 AJAX를 사용했고, (사진 6)을 보면 웹페이지 에 query들이 100ms 이하인 것을 확인 할 수 있다.
(사진 7)을 보면 javascript로 web server를 구현할 때 AJAX를 적용한 코드를 볼 수 있다. 코드를 간략하게 설명하자면 우선 AJAX문을 1초에 한번 씩 실행하도록 설정한다. AJAX 문에 대해 간략하게 설명하자면 데이터를 load하기 위한 php 페이지를 불러온 후, 전송방식을 post로 설정하고, DB에서 받아온 json 형식의 data를 parsing해서 실시간 값

변화가 필요한 각 함수에 할당하는 것으로 구성되어 있다.

(사진 6) 웹페이지 네트워크 트래픽 | (사진 7) AJAX 적용 코드

- 4 -

다음은 하드웨어 구현 사진이다. (사진 8)은 자동차의 운행 정보 데이터를 생성해주 는 simulator이다. 사진 가운데에 esp 32가 있다. 좌측에는 고장진단코드를 on/off 할 수 있는 스위치가 있으며, 우측에는 자동차 운행 데이터 값에 변화를 줄 수 있게 가변저항 이 달려있다. (사진 9)는 자동차의 값을 받는 Translator이다. 사진 위쪽에 있는 것은 Can

Transceiver이고, 아래에 있는 것은 esp 32이다. 자동차 simulator와 can 통신을 통해 자 동차 data를 받아온다.


(사진 8) 자동차 Simulator


(사진 9) 자동차 Translator

Ⅵ. 결론 및 기대 효과

본 작품에서는 운전자의 차량 점검과 관리를 위한 IoT를 이용한 차량정보 전송 및 활용 기술을 구현하였다. 차량과 IoT 장비인 ESP32간에 CAN, OBD2, UDS를 이용하여 차량의 운행 데이터를 수신하고 적절히 전처리하여 제공하였다. MQTT를 이용해 IoT 환경에서 저 전력 통신이 가능하게 하였고, AJAX를 활용하여 기존의 통신 지연을 100ms 이하로 줄여 실시간으로 이용자가 데이터를 볼 수 있게 하였다. 현재 본 서비스는 차량 운행 정보, 그래 프 통계, 차량 부품 교체 정보, 고장 정보, 급감속 및 급가속 등을 제공하고 있다. 향후 본 작품에서 제안된 시스템의 접근성 및 편리성을 높여 이용자가 더 쉽게 사용할

수 있게 할 것이며 자가 수리 방법, 이용자 커뮤니티 등 과 같은 이용자를 위한 추가 서
비스를 개발할 것이다. | Ⅶ. 후기

프로젝트 수행을 통해 기존에 잘 알지 못 했던 새로운 프로토콜인 CAN과 다양 한 통신 프로토콜(UDS, OBD, HTTP, MQTT)에 대해 공부할 수 있는 기회가 되 었고, ESP32의 사용법과 활용 방안에 대해 학습할 수 있는 의미있는 시간이였습 니다. 작품을 제작하는 도중 can통신에 문제가 생기고 시뮬레이터 제작중 문제가 생기는 등 크고 작은 문제가 생겼지만 팀원들과 같은 목표를 향해 효율적으로 협 업하고 문제를 해결해 나가는 과정을 통해 한발 더 성장함을 느꼈습니다.

- 5 -

Ⅷ. 참고 문헌

[1] Seo-Kyung Lee, Jae-Yong Lee, Dong-Hyun Kim, Kwang-Joo Choi, Jae-IlJung,CAN Communication System using CAN Protocol, Korea Information Processing Society, Republic of Korea, 2006, 4
[2] M. Farsi, K. Ratcliff and M. Barbosa, "An overview of controller area network," in Computing & Control Engineering Journal, vol. 10, no.3,pp.113-120,June 1999, doi: 10.1049/cce:19990304
[3] Assawinjaipetch, Panuwat, et al. "Unified Diagnostic Services Protocol Implementation in an Engine Control Unit." (2013).
[4] Pillar, Duane R. "Equipment service vehicle having on-board diagnostic system." U.S. Patent No. 6,553,290. 22 Apr. 2003.
[5] L. Almeida, P. Pedreiras and J. A. G. Fonseca, "The FTT-CAN protocol: why and
how," | in | IEEE | Transactions | on | Industrial | Electronics, | vol.49, | no6, | pp.
1189-1201,Dec.2002,doi: 10.1109/TIE.2002.804967.

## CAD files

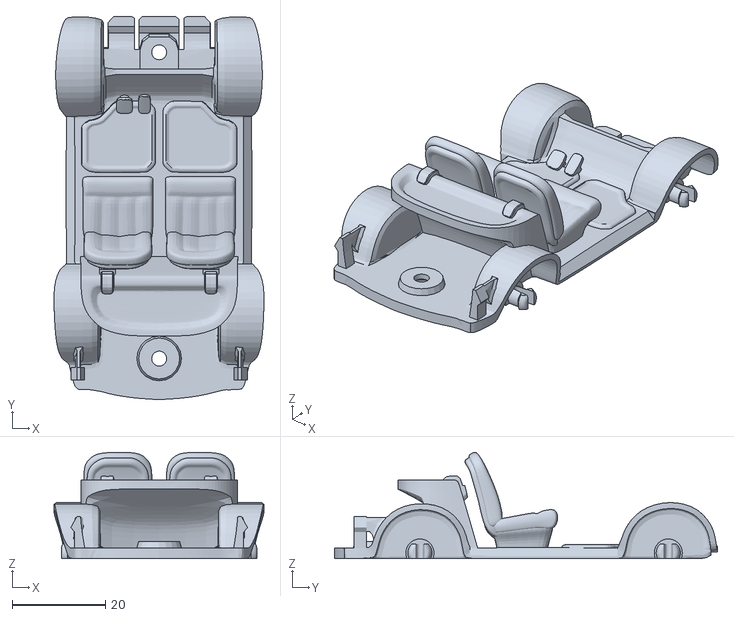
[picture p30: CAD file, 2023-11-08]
main/3D Design folder/Pony_Car_Bottom.stl
45.1 x 82.3 x 22.8

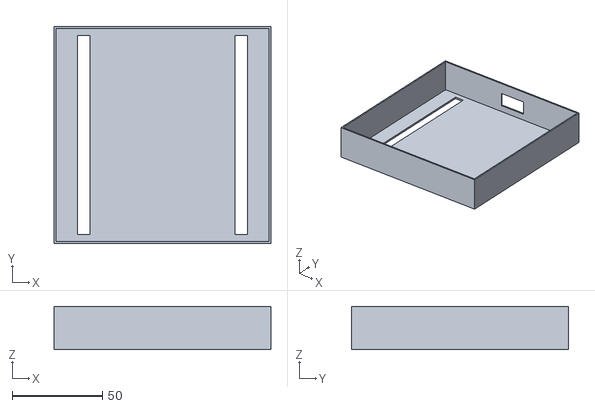
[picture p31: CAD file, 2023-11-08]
main/3D Design folder/sumulator_box.stl
120.0 x 120.0 x 24.0

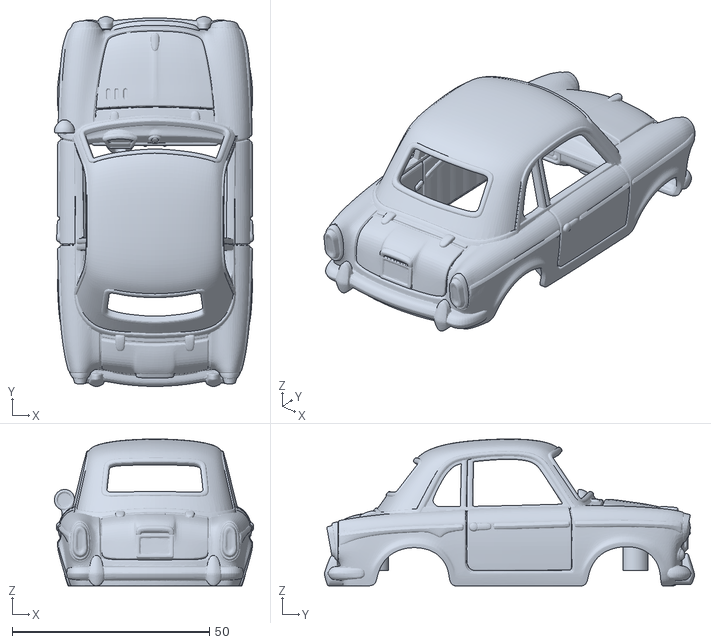
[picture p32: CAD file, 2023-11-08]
main/3D Design folder/Pony_Car_Body.stl
50.4 x 93.7 x 37.2

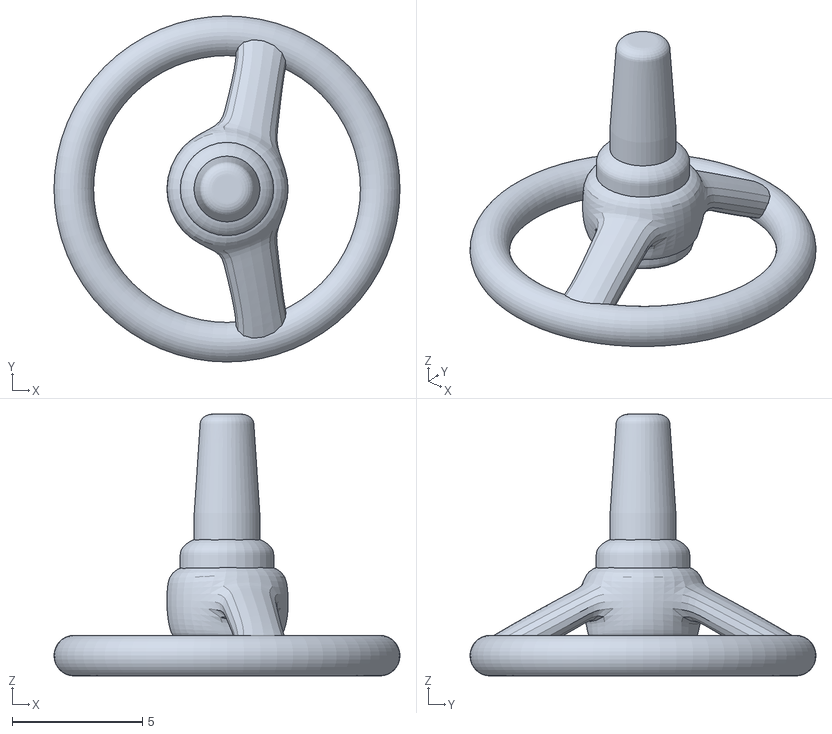
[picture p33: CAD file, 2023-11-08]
main/3D Design folder/Pony_Car_Steering.STL
13.3 x 13.3 x 10.1

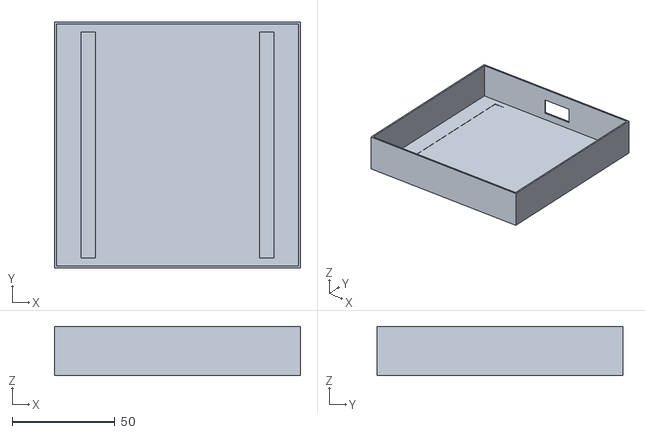
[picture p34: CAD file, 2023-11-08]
main/3D Design folder/translator_box.stl
120.0 x 120.0 x 24.0

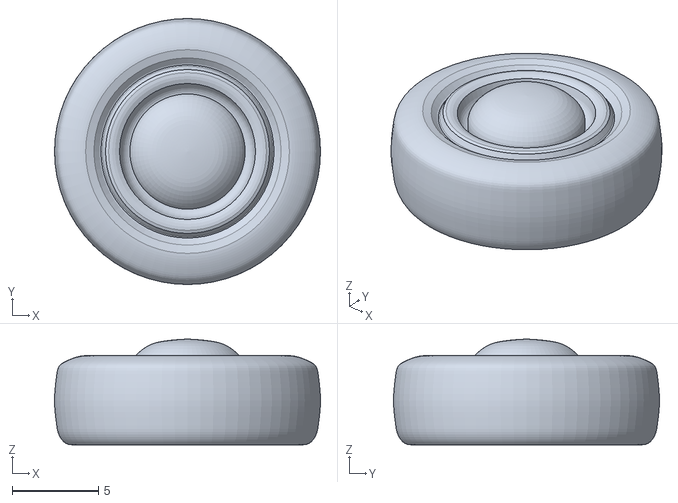
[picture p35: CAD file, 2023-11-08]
main/3D Design folder/Pony_Car_Wheel.STL
15.5 x 15.5 x 6.16

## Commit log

2023-11-08 Create esp32_can_library
2023-11-08 Add files via upload
    ESP32 UDS Library
2024-01-27 README 수정
2024-01-27 발표자료 및 프로젝트 설계서 파일 추가
2024-01-27 파일명 수정
2024-01-27 pdf 파일 추가
2024-01-27 pdf 파일명 변경
2024-01-27 paper 추가
